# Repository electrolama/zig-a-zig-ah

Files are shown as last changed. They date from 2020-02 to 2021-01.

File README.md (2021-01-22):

# zig-a-zig-ah

zig-a-zig-ah! (zzh, for short) is little USB-stick form factor dev board for multiprotocol RF tinkering. It utilises the TI CC2652R multi-standard wireless MCU and a USB-UART chip with a few more goodies.

Details at [electrolama.com/p/zzh](https://electrolama.com/projects/zig-a-zig-ah/).

Pre-assembled boards for sale [on our Tindie store](https://www.tindie.com/stores/electrolama/).

**Need help with your Tindie purchase?** Please send an email to support@electrolama.com. Github issues are not the right place for customer support and we do not monitor them.

zzh is designed by Electrolama / Omer Kilic and licensed under the [Solderpad Hardware License 2.0](https://solderpad.org/licenses/SHL-2.0/).

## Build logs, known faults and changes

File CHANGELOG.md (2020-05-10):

Revision A - 10/05/2020
- Initial release

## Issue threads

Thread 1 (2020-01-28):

cc2652rb, baw resonator

zigastegu, 2020-01-28:
Hi, it seems RB does not need XTAL, as it has Integrated Bulk Acoustic Wave (BAW) resonator.
Don't know about price difference and avalability.
Would it make a difference for pcb size?
https://www.ti.com/sitesearch/docs/universalsearch.tsp?searchTerm=cc2652rb

omerk, 2020-02-01:
Hey @zigastegu,

Looks like samples are available but not GA just yet, price comparison from the TI Store:

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

PCB real estate wise, doesn't make a huge difference for zzh as the form factor is dictated by the [enclosure chosen](https://twitter.com/OmerK/status/1219025454344146945).

Pushed the draft design files in the repo, let me know if you spot anything out of the ordinary :-)

Closed 2020-02-01.

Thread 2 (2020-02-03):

Somebody tried it?

guitar9, 2020-02-03:
Does somebody tried it out?
Does it work?
What are the plans for future?

sermayoral, 2020-02-06:
@guitar9 the device is in desing stage, so it does not work yet, but it promises... :-)

omerk, 2020-02-16:
That is correct, waiting on PCBs and parts to verify the design at the moment.

Keep an eye on [this Twitter thread](https://twitter.com/OmerK/status/1212864418155028480) for the latest info.

Closed 2020-02-16.

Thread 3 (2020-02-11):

Help components eletronics

pedroborges1, 2020-02-11:
Good,  i am interested in this zigbee pen Zig-a-zig-ah.

you can send me a list of the electronic components you used ?

how do you flash this zigbee pen Zig-a-zig-ah ?

omerk, 2020-02-16:
Hi @pedroborges1,

This is an untested, work-in-progress design. If you're interested in the BOM, the design files are in the repo and you can open them with EAGLE.

Keep an eye on [this Twitter thread](https://twitter.com/OmerK/status/1212864418155028480) for the latest info.

pedroborges1, 2020-02-16:
thanks you ,

I already have the  zig-a-zig-ah[1]/ Revision A[2] eagle file .

but there is another folder name debug-adapter.

I just need the zig-a-zig-ah / revision A ?

the file is not there Bom ?

Citando Omer Kilic <notifications@github.com>:

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

Ligações:
---------
[1] https://github.com/electrolama/zig-a-zig-ah
[2] https://github.com/electrolama/zig-a-zig-ah/tree/master/Revision%20A
[3] https://github.com/pedroborges1
[4] https://twitter.com/OmerK/status/1212864418155028480
[5]
https://github.com/electrolama/zig-a-zig-ah/issues/3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
[6]
https://github.com/notifications/unsubscribe-auth/AOQ2NE62XLFQWUG6HLLSLVLRDF3IVANCNFSM4KS72SWQ

omerk, 2020-02-16:
As I've said, this is still a work in progress so I have not yet released anything other than the currently untested design files. If you're interested in building one at this stage you are going to have to go through what is in the repo and figure it out yourself.

pedroborges1, 2020-02-16:
thank you ,when you are finished let me know .

Citando Omer Kilic <notifications@github.com>:

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

Ligações:
---------
[1]
https://github.com/electrolama/zig-a-zig-ah/issues/3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
[2]
https://github.com/notifications/unsubscribe-auth/AOQ2NE3PXWLA5DXF66ANX23RDG6BFANCNFSM4KS72SWQ

pedroborges1, 2020-02-18:
good, but have you tested this zig-a-zig-ah?

how did the flash zig-a-zig -ah ?

Citando Omer Kilic <notifications@github.com>:

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

Ligações:
---------
[1]
https://github.com/electrolama/zig-a-zig-ah/issues/3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
[2]
https://github.com/notifications/unsubscribe-auth/AOQ2NE3PXWLA5DXF66ANX23RDG6BFANCNFSM4KS72SWQ

pedroborges1, 2020-07-01:
good, i used an ikea repeater for the zigbee network, but even so a
sensor sometimes stops working.

I think the signal doesn’t reach that sensor well, which is the one
that’s farthest away.

some solution to improve this ?
 

Citando pedro <pedrofilipe32@sapo.pt>:

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

Ligações:
---------
[1]
https://github.com/electrolama/zig-a-zig-ah/issues/3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
[2]
https://github.com/notifications/unsubscribe-auth/AOQ2NE3PXWLA5DXF66ANX23RDG6BFANCNFSM4KS72SWQ

Closed 2020-02-16.

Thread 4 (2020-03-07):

Raspberry hat

pimvanpelt, 2020-03-07:
Thanks for your work @omerk and I've subscribed to your mailing list for updates when you've tested your first Revision A in this repo.
When you're a bit further along, I suggest building a raspberry pi hat, as many folks will be using those to build their zigbee networks. I can contribute it (design it, order/test them and report back). Let me know if you'd be willing to accept that and I'll wait for you to confirm your current approach and send you a PR.
I think it would be good for the community to have these 26x2 boards in the same place and using the same firmware/pinout/etc.

omerk, 2020-03-08:
Hey @pimvanpelt, thanks for dropping by!

I've been busy testing today, you can find an update [on the project page](https://electrolama.com/projects/zig-a-zig-ah/).

With regards to the Raspberry Pi hat, not sure if you have seen [this](https://electrolama.com/projects/zoe/)? I have not yet pushed it online yet but I do have a version of zoe (zoe2, if you will) that merges the two projects together. Does that sound similar to what you had in mind?

pimvanpelt, 2020-03-09:
Yes, your zoe2 as a marriage of CC2652 and POE adapter looks like a
wonderful outcome to me, particularly because I do indeed use POE in my own
deployment.
Feel free to close this now, or once you have a prototype. Happy to buy a
dozen or so from you or make myself, as you prefer.

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

--
Pim van Pelt <pim@ipng.nl>
PBVP1-RIPE - http://www.ipng.nl/

omerk, 2020-03-10:
Keep an eye on https://electrolama.com or [Subscribe to the mailing list](https://mailchi.mp/1746be86dd81/electrolama) to get updates when I publish new projects.

Closed 2020-03-10.

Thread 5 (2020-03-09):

[SUGGESTION] Team up with zigpy-cc and/or zigpy-znp projects to beta-test Zig-a-zig-ah with ZHA in Home Assistrant

Hedda, 2020-03-09:
@omerk Can I suggest that @electrolama try to reach out to @sanyatuning & @Adminiuga & @puddly about collaborating and teaming up to beta-test your "Zig-a-zig-ah!" USB-stick together with the zigpy-cc and/or zigpy-znp projects for using Texas Instruments CC2652 based Zigbee adapters with the ZHA integration in Home Assistant?

- https://github.com/sanyatuning/zigpy-cc/
- https://github.com/zha-ng/zigpy-znp
- https://github.com/puddly/zigpy-znp

As I understand it zig-a-zig-ah by Electrolama / Omer Kilic as well as zigpy-cc by @sanyatuning and zigpy-znp @Adminiuga & @puddly are only spare-time hobby projects but still I think that teaming up might give both projects some positive recognition in the Home Assistant community which might attract more developers and willing alpha/beta-testers from the community to come help out with both these projects which in the long run could benefit all users wanting ZHA to become more mature and working with more hardware than today.

- https://www.home-assistant.io/components/zha/

marv, 2020-03-09:
Great suggestion! I'd love to get involved as well if I can be of any help. I've been following both projects for the last week with great interest and been contemplating about ordering some zig-a-zig-ah boards myself to test things, but thought I wait for @omerk first test results. Now that the design is verified to work, i'll try to find time for that

puddly, 2020-03-09:
The [TI LAUNCHXL-CC26X2R1](https://www.zigbee2mqtt.io/information/supported_adapters.html#texas-instruments-cc26x2r1) uses the exact same SoC and people have had good luck with it using [zigbee2mqtt/zigpy-cc](https://github.com/Koenkk/zigbee2mqtt/issues/1429). It's been powering my entire network of 30+ devices for many weeks now so this adapter *should* work out-of-the-box when flashed with the same firmware.

Gamester17, 2020-03-10:
This kind of relate to my suggestion to donate money to existing Zigpy and ZHA developers for them to buy TI CC based hardware in order to be able to help with the development, see here:

https://github.com/zigpy/zigpy/issues/276

My thinking is if more developers with proven personal interest Zigpy or ZHA owed TI CC hardware then they might have a greater incentive to volunteer their time and skill for developing this.

I am not a developer myself, however, I am willing to make a small donation for this cause because believe that the concept of Zigpy or ZHA for Home Assistant will benefit the community in the long.

omerk, 2020-03-10:
Hey all,

Definitely keen to collaborate (power of open source hardware and software!) and can happily provide some prototypes if and when you have time to test it with your corresponding projects.

I am reasonably confident with the design but will be doing some further testing this weekend and have enough parts for a couple of prototypes that I can hand populate/reflow. As you can imagine hand populating these boards take a good amount of time so the first few units are very precious 😄

Feel free to reach out (<myfirstname>@electrolama.com) if you'd like to play with some prototype hardware!

Cheers,
Omer.

Hedda, 2021-01-13:
@omerk Can I suggest that you reach out to @puddly and @sanyatuning  about prototype/alpha/beta/reference-testing your upcoming "zzh-p" (CC2652P USB) and "zoe2" (CC1352P shield) adapters together with zigpy? Please also see https://github.com/zigpy/zigpy-znp/issues/55

Closed 2020-03-10.

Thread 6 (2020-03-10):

[SUGGESTION] Market and sell an initial of batch Zig-a-zig-ah! adapters via the Crowd Supply site?

Hedda, 2020-03-10:
@omerk I like to suggest that you market and sell an initial small batch of your Zig-a-zig-ah! USB-adapters via the **Crowd Supply** crowdsourcing site for electronics hardware at [crowdsupply.com](https://www.crowdsupply.com)

- https://www.crowdsupply.com

@omerk I understand that you already have existing plans to sell hardware via Tindie. Crowd Supply is similar but different than Tindie in that Crowd Supply is not just a marketplace but specifically, a crowdsourcing platform which has staff that will actively help you with advice on running a crowdsourcing campaign for funding, manufacturing, and marketing.

Most importantly, Crowd Supply has a great international community so I think that also launching a crowdsourcing campaign on Crowd Supply would help you grow a much larger community around Electrolama and the Zig-a-zig-ah project. Many electronics products have initially first launched on Crowd Supply then only after proven successful and gaining experience of running a small crowdsourcing campaign with a smaller batch next launch larger crowdsourcing campaigns with a more finished version of the same or similar products on Kickstarter and/or Indiegogo.

- https://www.crowdsupply.com/about

I have no personal affiliations with **Crowd Supply** or its owers/staff, but I backed a couple of projects there myself and know that their site is meant exactly for helping crowdsource funds and initial launch of a small batch of this type of early version hobby-class hardware kits meant for developers and advanced users who are willing to accept bleeding-edge hardware which might not yet be a finished product.

Personally I can recommend that you compare this μArt hardware by Karoly Pados which I backed:

- https://www.crowdsupply.com/pylo/muart

I think that his launch for a small initial batch of μArt (pronounced "Muart") on Crowd Supply was a perfect example of how a crowdsourcing campaign for this type of niche electronics hardware should be handled before its a mature product.

omerk, 2020-03-10:
Hey @Hedda, thanks for reaching out.

I am familiar with Crowdsupply and looking at distribution/logistics is on my list of things to do for the weekend, after I do some further testing with the prototypes so that I can issue files for manufacturing a small batch.

Getting the design verified is my current priority, rest will follow soon after 😄

Cheers!

Hedda, 2020-03-11:
@omerk Cool! Regardless if you go with that or not I still highly recommend that you read through μArt updates by Karoly Pados as a great example on how to run and update the community during such a campaign, so do checkout update history here https://www.crowdsupply.com/pylo/muart/updates

Closed 2020-03-10.

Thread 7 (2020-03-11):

[NEW PROJECT SUGGESTION] Zigbee 3.0 and Z-Wave 700 platform series combo USB-stick

Hedda, 2020-03-11:
Hi Omar! I follow you on Electrolama, hope it is OK to submit this as a suggestion for a new project.

Suggest you consider making a "combo" USB-stick supporting both Zigbee 3.0 & Z-Wave 700 series.

I believe that should be a good market for a "combo" USB-stick if Zigbee 3.0 coordinator & Z-Wave 700 (Gen7) platform series controller could be offered as a combination on the same USB-stick and it was less expensive to buy then to buy a separate USB-sticks for each protocol. As you probably know both Zigbee 3.0 and the Z-Wave 700 platform series are backwards compatible with previous versions of those protocols, so a such combo USB-stick could probably be marketed as the most compatible USB-stick for DIY home automation controllers in the world.

Not sure if you knew but there is a very popular combo USB-stick already available, it however only supports Zigbee HA 1.2 and Z-Wave 500 (Gen5) series; Nortek GoControl QuickStick Combo Model HUSBZB-1 (Zigbee & Z-Wave USB Adapter) is supported natively by Home Assistant's built-in ZHA and Z-Wave integrations. As I understand it, that HUSBZB-1 is based on two separate Silicon Labs chips for Zigbee and Z-Wave, and it presents itself to the operating system as two separate serial adapters. "The Model HUSBZB-1 is a USB stick that houses both a Z-Wave and Zigbee radio. Designed for OEMs that want to provide dual functionality when being used with a host device.":

https://www.nortekcontrol.com/products/2gig/husbzb-1-gocontrol-quickstick-combo/

Silicon Labs released a UZB-7 / UZB7 based on EFR32ZG14 as a reference design for making Z-Wave 700 platform series USB-stick controllers.

https://www.silabs.com/documents/public/data-sheets/DSH14483.pdf

Silicon Labs also has Zigbee chips like EFR32MG13 (example: EFR32MG13P732F512GM32-C) and others design to be used in a Zigbee coordinator.

https://www.silabs.com/wireless/zigbee

As I understand it, both those chips belong to the "Gecko" series by Silicon Labs.

Anyway, chips from Silicon Labs would be the obvious choice for a combo USB-stick since they own the Z-Wave specification and are also according to them the leading provider of Zigbee solutions as as as for Bluetooth solutions.

https://www.silabs.com/products/wireless/mesh-networking/z-wave/700-platform

PS: I don't have the skills to contribute to a hardware design but I would definitely buy one or back such a combo USB-stick if was launched as a campaign on a popular global crowdfunding platform.

omerk, 2020-03-25:
Thanks for the links and background info @Hedda

I must admit I am a lot more familiar with Zigbee than Z-Wave so that is what I am focusing on with this design but once zzh gets a bit more mature and I am looking for my next weekend project, I will certainly revisit this discussion!

Closed 2020-03-25.

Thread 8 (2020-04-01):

[REQUEST] Create a small adapter-board for connecting the standard CC-DEVPACK-DEBUG board to Zig-a-zig-ah USB-stick?

Hedda, 2020-04-01:
@omerk Can I suggest or request that you please consider also creating a matching small adapter-board for connecting Texas Instruments standard CC-DEVPACK-DEBUG board (XDS110 Debug Probe) to Zig-a-zig-ah USB stick?

CC-DEVPACK-DEBUG board meaning the XDS110 Debug Probe that is also included in the CC2652 Launchpad board (LAUNCHXL-CC26X2R1):

- https://www.digikey.com/product-detail/en/texas-instruments/CC-DEVPACK-DEBUG/296-42039-ND/5232199
- https://processors.wiki.ti.com/index.php?title=CC13xx_CC26xx_Tools_Overview#XDS110_2

That is since the Zig-a-zig-ah USB-stick has a non-standard debug-port it would preferably be nice to have a simple adapter-board for connecting Texas Instruments standard CC-DEVPACK-DEBUG board to it for debugging purposes. Perhaps an adapter similar to that is commonly sold with CC2531 USB sniffer dongles for connecting a CC-Debugger to them, (those referred to as "downloader cable" by Zigbee2mqtt):

 - https://www.zigbee2mqtt.io/getting_started/what_do_i_need.html
 - https://www.zigbee2mqtt.io/getting_started/flashing_the_cc2531.html

For reference; @turboproc mentioned here that he has also designed/created a small adapter-board for connecting the standard CC-DEVPACK-DEBUG board to his own prototype CC2652 USB dongle:

https://github.com/Koenkk/zigbee2mqtt/issues/1429#issuecomment-606814358

turboproc, 2020-04-01:
Regarding the adapter, that's indeed what I did: tiny  board that clicks in the CC-DEVPACK-DEBUG board and has that connects with a small cable (2 x 3 pin 1.27mm pitch) into the dongle. Used the same pin-out on that side at he Zig-a-zig-ah to avoid again another non standard solution.

Hedda, 2020-04-01:
@turboproc Are you maybe willing to share your design layout & BOM, etc. as open-source hardware?

turboproc, 2020-04-01:
Sure, no problem. Give me some time to push it to Github.

omerk, 2020-04-01:
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

I've committed the files for this adapter [2 months ago](https://github.com/electrolama/zig-a-zig-ah/tree/master/Debug-Adapter), should have checked the repo @turboproc :-)

Closed 2020-04-01.

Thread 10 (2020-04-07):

[INFORMATION] Zig-a-zig-ah USB-stick should also be compatible with turboproc's Zigbee dongle adapter for TI CC-DEVPACK-DEBUG board

Hedda, 2020-04-07:
@omerk FYI, just a piece of compatibility information, the Zig-a-zig-ah USB-stick should also be compatible with the Zigbee dongle adapter for TI CC-DEVPACK-DEBUG board designed by @turboproc

- https://github.com/turboproc/Zigbee-dongle-adapter

The 6 pin connector on the Zig-a-zig-ah USB-stick should also match both the [CC1352-based Zigbee USB-dongle](https://github.com/turboproc/Zigbee-USB-dongle) by @turboproc and the [CC2652-based Zig-a-zig-ah USB-stick](https://github.com/electrolama/zig-a-zig-ah) by @omerk allowing easy connection to the TI CC-DEVPACK-DEBUG board that allow these Zigbee USB dongles to be programmed through the CJTAG interface.

- https://github.com/turboproc/Zigbee-USB-dongle
- https://github.com/electrolama/zig-a-zig-ah

omerk, 2020-05-07:
Good to know although there is already a [debug-adapter board in the repo](https://github.com/electrolama/zig-a-zig-ah/tree/master/Debug-Adapter).

Closed 2020-05-07.

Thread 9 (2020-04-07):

[REQUEST] CAD-design of CC2652 USB-stick housing/enclosure and STL-files for editing and 3D-printing?

Hedda, 2020-04-07:
@omerk  Anyone working on an open-source CAD-design of a USB-stick housing/enclosure specifically made for CC2652 USB-sticks and if so would be willing to share their designs in STL file-format to enabling editing the design by others and 3D-printing?

One can, for example, get many designs and files for CC2531-based USB-dongles/USB-adapters (with or without antenna) on Thingiverse, example:

- https://www.thingiverse.com/thing:3948643
- https://www.thingiverse.com/thing:3646828
- https://www.thingiverse.com/thing:3532598
- https://www.thingiverse.com/thing:3731958

One can also buy professionally made injection moulding housings/enclosures from China via Alibaba or Aliexpress that one can take inspiration from, example:

- https://aliexpress.com/item/4000134201124.html
  - https://ae01.alicdn.com/kf/Hfb070d72fc45440497dce7d04e59d6b7d.jpg
- https://aliexpress.com/item/32855419632.html
  - https://ae01.alicdn.com/kf/H326a2ad3cfe64a318083102b0df62cd5N.jpg
  - https://ae01.alicdn.com/kf/H01eca8f47cd64bfd975738c1a4c30553i.jpg
- https://aliexpress.com/item/33007327270.html
- https://aliexpress.com/item/32852997963.html
- https://aliexpress.com/item/32690180597.html
- https://aliexpress.com/item/32847892743.html
  - https://ae01.alicdn.com/kf/HTB1K83IeXHM8KJjSZFwq6AibXXaD.jpg

By the way, I am not sure about English terminology for this, when talking about an exterior/outer protective covering for interior/inner electronic equipment in the specific context of a USB-dongle/USB-adapter like the Zig-a-zig-ah USB-stick, is the keyword called; enclosure, housing, casing, cover, case, box, shell, or another descriptive name that might be more correct?

- https://en.wikipedia.org/wiki/Housing_(engineering)
- https://en.wikipedia.org/wiki/Electrical_enclosure
- https://en.wikipedia.org/wiki/Computer_case

Hedda, 2020-04-07:
Disclaimer: I have also posted the same request/question to @turboproc on https://github.com/turboproc/Zigbee-dongle-adapter/issues/1

omerk, 2020-05-07:
zzh uses a very common off-the-shelf "usb shell" enclosure from China so unfortunately I don't have any STLs to share as I didn't design it.

Happy to accept contributions from anyone with the CAD experience to release an open-source enclosure for it though, ping me if you need any dimensions/3D data exported.

Closed 2020-05-07.

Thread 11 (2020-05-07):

[QUESTIONS] Plans on manufacturing, crowdfunding and/or selling none-prototype version of Zig-a-zig-ah (ZZH) dongles?

Hedda, 2020-05-07:
@omerk Read in https://github.com/Koenkk/zigbee2mqtt/issues/1429 that you plan on setting up a Tindie store for Zig-a-zig-ah (ZZH) dongles and was curious on your plans for selling and shipping the USB-stick adapter as a "finished plug-and-play product" there as not seen any updates on your Twitter account or the Electrolama site.

Mostly I was wondering if you already have funding and manufacturers lined up for making a finished product or are you doing a crowdfunding campaign? Also, where do you think you will be shipping it from? I'm asking for myself as an EU (European Union) customer, Sweden to be exact.

Regardless of how you proceed, please ship the product with a nice plastic housing/enclosure/shell/chassis which will be easy to open and close for modification, as related to the request in https://github.com/electrolama/zig-a-zig-ah/issues/9 you can buy professionally made injection moulding housings/enclosures from China but I am not sure they are to open and close over and over again without breaking the fastenings.

zigastegu, 2020-05-07:
Onboard bootloader sholod enable flashing new fw without opening enclosure or so I have read on: https://electrolama.com/projects/zig-a-zig-ah/

Do you have any other use cases for opening enclosure?

omerk, 2020-05-07:
Hi @Hedda,

Not interested in crowdfunding, the first batch should go up on Tindie at some point this weekend (at least, submitted for their approval). Sign up to the [mailing list](https://electrolama.com/list) to get an update when everything goes live.

Here's a photo of the enclosure and the antenna that will ship with the units purchased on Tindie, it's a snug fit case but certainly would last the few times that you might need to open the unit if you want to program the device

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

omerk, 2020-05-07:
@zigastegu If you want to program the board, you will still need to press the "BSL" button as you're plugging the device in to trigger the bootloader (requiring you to open the case).

I've asked about triggering the bootloader from a running program on the [TI forums](https://e2e.ti.com/support/wireless-connectivity/zigbee-and-thread/f/158/t/902829), let's see what they say.

Realistically, unless you are a firmware developer you shouldn't have to worry about opening the case to access the button as once you program the board and set up your network, you will leave things as they are. If you are indeed developing firmware and don't want to worry about the case, I suggest using the bare board without the case.

mar565, 2020-05-07:
@omerk can you already Tell us the price?

omerk, 2020-05-10:
Listing submitted to Tindie, once approved it will go live on https://www.tindie.com/products/electrolama/zzh-cc2652r-multiprotocol-rf-stick/

Hedda, 2020-05-11:
> Onboard bootloader should enable flashing new fw without opening enclosure or so I have read on: https://electrolama.com/projects/zig-a-zig-ah/
>
> Do you have any other use cases for opening enclosure?

Firmware developers with the debug adapter require access to the board for debugging, see:

https://github.com/electrolama/zig-a-zig-ah/tree/master/Debug-Adapter

Also, if you brick it then you need to press the "BSL" button to trigger boot to the bootloader.

Hedda, 2020-05-12:
@omerk Out of stock / Sold out already? Checked yesterday before went to bed and was not live then:

https://www.tindie.com/products/electrolama/zzh-cc2652r-multiprotocol-rf-stick/

Closed 2020-05-10.

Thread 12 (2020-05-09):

Some suggestions for a future revision of the board

puddly, 2020-05-09:
(copied from https://github.com/zha-ng/zigpy-znp/issues/10)

Thanks for the awesome board! I'm seeing an average LQI improvement of 30% compared to the bulkier LAUNCHXL-CC26X2R1.

Here are some suggestions for future revisions of the board:

1. Would you consider using a USB-serial chip by FTDI or Silicon Labs? The CH340 is the only USB-serial chip that consistently causes a kernel panic on my MacBook and is overall unreliable in my experiences with random dev kits. I'm running kernel 4.14.176 on my ODROID XU4 and the ZZH stick needs to be re-plugged a few times in a row to respond to any serial communications, unless it's plugged into a USB extender (!?). I have half a dozen other USB devices plugged in at any given time and have never had this problem except with devices using the CH340.

2. While a minor detail, holding down the flash button while inserting the stick is difficult with the button mounted horizontally and near the male USB-A connector. It would be a bit easier to flash if the button was mounted near the rear of the board next to the antenna.

3. I'm not sure if there's a huge price difference for you but including one of those bendable and rotatable 2.4Ghz antennas would make it easier to mount. Most of my USB devices are plugged into a powered hub with the ports sticking straight up and the fixed right-angle antenna connector makes mounting a little difficult.

If I end up making a case for it I'll definitely make a pull request with the STL. If you have a moment, could you upload an SVG version of your logo to this repository?

omerk, 2020-05-10:
Hey @puddly, great to hear you are up and running and thanks for the comments!

Addressing your points:

1) zzh originally had CP2102N but had to find a replacement as it simply wouldn't fit the layout once I picked the enclosure. I did look at FT230X and FT234XD (the 'runner-up') but at many times the cost of CH340E and with much better driver support over the last year or so for CH340E, the decision was made.

The assumption here is that majority of the users of zzh will be using Linux and probably on a popular SBC (like a Raspberry Pi) that will have an up-to-date kernel. In the many months of testing I did with both Raspberry Pi and an Ubuntu box, I never had driver issues. I know @Koenkk had an issue initially with the drivers but that was solved with him updating his box.

Now of course this isn't an attempt at not acknowledging the issues you are having, just providing the rationale behind the design decision. For macOS, unfortunately I can't really comment as I don't have any Macs around but for your XU4, can I ask perhaps you give a more recent kernel (if available) a go? [Some recent fixes in the kernel driver](https://github.com/torvalds/linux/commits/master/drivers/usb/serial/ch341.c) did improve the situation quite a bit. If you have the willpower and the time to tinker with the kernel on your XU4, perhaps we can get to the bottom of it? In the meantime, I can happily send you the hacked-with-the-FT234XD board I have in my box of prototypes. It won't look pretty but it sure is another collectors' piece :-)

2) I ordered a dozen or so button samples, some side mounted ones included, but it came down to picking this current one because it had a nice click and actually felt like a button (a problem with tiny buttons!). I actually wanted to use the side mounted one used on the TI Launchpads but not enough space :(

3) The antenna I picked sits nicely in the middle of a size-cost-performance triangle, size being the deciding factor. I couldn't find a small-enough 'bendable' antenna so decided to go for this fixed version instead, based on the assumption that the following would be the typical use case:

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

I am still looking for a small *and* bendable antenna that is sensibly priced, once I find it we can then issue it as a running change for boards shipped. The beauty of the detachable antenna is that if it gets on your nerves too much, you can change it.

Always difficult defining a product to satisfy all use cases and it comes down to making assumptions (like the ones discussed above) and hoping you were right. I guess we will find out given that this is an open source project with an issue tracker :-)

Cheers!

Adminiuga, 2020-05-10:
well, since there's SMA connector you could get any antenna you'd like aliexpress. Just make sure it is SMA Male connector for antenna.

eg https://www.aliexpress.com/item/33044689298.html

Adminiuga, 2020-05-11:
@puddly are you on armbian? I'm running my prod on xu4 as well and this is going be a show stopper. Gonna try switching kernels to 5.4

puddly, 2020-05-11:
1. My development and production setup is definitely not common so no worries, I'm just documenting the issues I have. If I run into it again and figure out a way to fix it I'll post an update.

2. I was thinking just moving the button closer to the antenna, so you can keep it pressed more easily while inserting the stick. It does have pretty good tactile feedback for its size.

3. I just tested out one of those bendable antennas from a 2.4GHz wireless card and the LQI was reduced quite a bit, though not as much as with the right-angle antenna pointed the wrong way.

Hedda, 2020-05-11:
Possible to replace CH340E with one that has flashable EEPROM so strings/VID/PID can be customized?

Would be both more user-friendly, to be able to for example script plug-and-play auto-detection, and more professional if the description for the serial port device was shown as example:

 "Zig-a-zig-ah USB-dongle v1.0.0"

As per the original suggested in https://github.com/zha-ng/zigpy-znp/issues/10 by @Adminiuga

> @omerk is it possible to customize the USB-Serial chip, so it provides a more specific description for serial port device? Currently I"m getting generic:
> `usb-1a86_USB2.0-Serial-if00-port0 -> ../../ttyUSB0`

Hedda, 2020-05-11:
> If I end up making a case for it I'll definitely make a pull request with the STL. If you have a moment, could you upload an SVG version of your logo to this repository?

@puddly Please also see related CAD-design request in https://github.com/electrolama/zig-a-zig-ah/issues/9

Hedda, 2020-05-11:
> While a minor detail, holding down the flash button while inserting the stick is difficult with the button mounted horizontally and near the male USB-A connector. It would be a bit easier to flash if the button was mounted near the rear of the board next to the antenna.

@omerk Regardless of button location on the board, a tip follow the industry-standard design and drill a small hole through the enclosure/case where the button is located to let users be able to press the button with a paper-clip

https://www.google.com/search?q=paper+clip+reset+button&tbm=isch

Again, having a "Reset Hole" purposely design to be pressed via a paper-clip is the industry-standard.

Hedda, 2020-05-11:
SMA or RP-SMA (Reverse-Polarity SMA) is basic but important information when buying an antenna:

https://en.wikipedia.org/wiki/SMA_connector

@omerk Which exact type of SMA connector design does the ZZH board have on it?

Do ZZH board have a Standard-Polarity SMA or a Reverse-Polarity ("RP") SMA female connector?

> well, since there's SMA connector you could get any antenna you'd like aliexpress. Just make sure it is SMA Male connector for antenna.
>
> eg https://www.aliexpress.com/item/33044689298.html

I can personally recommend "Delock" branded Wi-Fi antennas which can be bought in EU & USA.

https://www.delock.com/produkte/G_1468_Antenna.html

I have no personal affiliations but in the European Union you can buy Delock antennas from Conrad

https://www.conrad.com

puddly, 2020-05-11:
Another issue I'm seeing (though probably not zzh-specific) is that I get nonstop routing and MAC failures with it plugged directly into my XU4. There are bulbs within a few feet of it I get errors such as these in response to any request, even with route discovery enabled:

```Python
AF.DataConfirm.Callback(Status=<Status.NwkNoRoute: 205>, Endpoint=1, TSN=18)
AF.DataConfirm.Callback(Status=<Status.MacChannelAccessFailure: 225>, Endpoint=1, TSN=15)
```
Plugging it into a hub an inch or two away fixes the issue. I'll try out some simple shielding and will see if it helps at all.

Adminiuga, 2020-05-11:
ChannnelAccessFailure  is pretty much a tail sign of RF interference. If it is fixed by keeping the board away from SBC, then we can conclude the noise is coming from the  SBC which is frankly quite expected.  ConBees are susceptible  to the very same issue and that's why they always recommend to use an usb extension cable.
I wonder how many people complaining about range issue, could fix them  by using an usb extension.  I assume all are susceptible to this issue, just some  adapters are not providing this feedback.

Hedda, 2020-05-12:
Tip regardless of antenna is to use at least a 1-meter USB-extension cable for all radio adapters. If use USB-extension cable then gets it away from most SBC or computers WiFi and Bluetooth interference.

Hedda, 2020-05-12:
@omerk here is a "must-read" article about analyzing antennas if want to be sure before deciding:

- https://tinkerman.cat/post/analyze-your-antennas-using-an-aai-n1201sa/

It recommends buying theN1201SA by Accuracy Agilty as is a cheap but incredibly useful tool:

- http://s.click.aliexpress.com/e/bVPlgjT6
- https://amzn.to/2VqBlW5

That article is written by Xose Pérez (a.k.a. Tinkerman) who also develops ESPurna FW for ESP8266:

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

sjorge, 2020-06-27:
> 1. Would you consider using a USB-serial chip by FTDI or Silicon Labs? The CH340 is the only USB-serial chip that consistently causes a kernel panic on my MacBook and is overall unreliable in my experiences with random dev kits. I'm running kernel 4.14.176 on my ODROID XU4 and the ZZH stick needs to be re-plugged a few times in a row to respond to any serial communications, unless it's plugged into a USB extender (!?). I have half a dozen other USB devices plugged in at any given time and have never had this problem except with devices using the CH340.

Just going to give this a +1 here too :) Omerk is already aware of my preference, as I am not using linux (or freebsd) I am currently trying to write a driver for CH340 and boy its and oddball chip.

omerk, 2020-06-27:
zzh-p will use FT231 that will allow us customise strings and also auto-reset/put device in BSL mode via DTR/RTS pins exposed.

No plans for change on zzh though.

copystring, 2020-06-27:
Nice. I was about to ask about this to allow nice udev rules (all CH340 have the same serial). Exciting!

svh1985, 2020-09-18:
I also have a small suggestion;
I'm not sure if the provided plastic case is custom designed or off-the-shelf, but adding a small hole to allow us to press the BSL button would be very nice. Getting the case off is hard and this makes programming possible without removing the case.

Hedda, 2021-01-13:
@omerk Any news on your CC2652P based "zzh-p" and if it will soon be available for sale or not?

omerk, 2021-01-22:
Hi all, lots of comments to address but as a summary:

There will be two versions zzh with CC2652P: zzhp and zzhp-lite. Both will use the same firmware, zzhp-lite will be module-based (PCB antenna) and zzhp will be a custom board similar to the first draft screenshot you linked above (external antenna). I've also managed to squeeze in a few more goodies in zzhp and will be updating the website soon. Release date not set yet but it's very soon.

@svh1985 and many others requested a pre-drilled hole. The last couple of (and all future) batches will ship with cases that are pre-drilled:

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

You'll also notice that we now have a swivel antenna, another requested feature.

Both drilled cases and that newer antenna were things I wanted from the get go but needed to hit a certain MOQ before I could get them. We're there now 🙂

Closed 2021-01-22.

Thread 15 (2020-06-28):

No Signal in Z2M when using a different antenna

kennymc-c, 2020-06-28:
When I connect the zzh to different antenna (dual band WiFi +9dbi), Z2M seems to have problems with reception. There are simply no signals coming in. According to dmesg, the adapter has been detected by the system. As soon as I reconnect it to the supplied antenna, the signal is coming back. Since I use the same type of antenna with a CC2530 router, I assume that the antenna itself is suitable for this. I have attached a zigbee-herdsmann debug log that might help:

https://pastebin.com/k4wAtciK

puddly, 2020-06-28:
The zzh has a female SMA connector. Make sure your antenna is not a male RP-SMA, which will still screw on but will not actually act as an antenna:

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

kennymc-c, 2020-06-28:
Thanks, that should be the reason. My antenna is also female. I just realized now when I saw the connection. Sorry, I could have figured it out myself.

Closed 2020-06-28.

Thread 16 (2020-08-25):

[SUGGESTION] Team up with pipiche38 who is developing a zigpy plugin for Domoticz

Hedda, 2020-08-25:
@omerk (Omer Kilic) Can I suggest that you (and @electrolama ) try to reach out to @pipiche38 (Patrick Pichon) about possible collaborating and teaming up to test your "Zig-a-zig-ah!" USB-stick together with the new Zigbee implementation for Domoticz that he is developing using [zigpy](https://github.com/zigpy/zigpy)?

* https://github.com/pipiche38/Domoticz-Zigpy/

Please also see respective suggested posted to pipiche38 here:

https://github.com/pipiche38/Domoticz-Zigpy/issues/1

If you omerk (Electrolama) could donate one or two of your "Zig-a-zig-ah!" USB-sticks to him then maybe he that can help @pipiche38 developing effort as it would give him the possibility to also test both [zigpy-cc](https://github.com/zigpy/zigpy-cc) and [zigpy-znp](https://github.com/zha-ng/zigpy-znp) radio libraries for zigpy to try out their compatibility with newer Texas Instruments CC2652 based Zigbee adapters as zigpy can support many different adapters. It could perhaps later even be used as a reference adapter. No strings attached of course as these are still hobby projects at their core with only one developer so far.

https://github.com/zigpy/zigpy

pipiche38 is still in a very early stage of developing his "Domoticz-Zigpy" plugin for [Domoticz](https://www.domoticz.com) (a free and open-source home automation software), I understand in fact the project is so a such early in development that is not yet usable, however, I read on Domoticz community forum that he currently only has access to ZiGate Zigbee adapters (this as pipiche38 is also the developer of an existing ZiGate plugin for Domoticz). So at least we know that pipiche38 already has the experience and skills to develop Zigbee plugins for Domoticz.

* https://github.com/pipiche38/Domoticz-Zigate-Wiki/blob/master/en-eng/Home.md

* https://www.domoticz.com/wiki/Zigate

As I understand it zig-a-zig-ah by Electrolama, zigpy, Domoticz, and this new "Domoticz-Zigpy" plugin are all only spare-time hobby projects but still, I think that teaming up might give all involved projects some positive recognition in the Domoticz community and the whole home automation scene in general which might attract more developers and willing alpha/beta-testers from the community to come to help out with all these involved projects which in the long run could benefit all users wanting Zigbee in Domoticz to become more mature and working with more Zigbee hardware dongles than it is today.

omerk, 2020-08-27:
@pipiche38 Happy to support a fellow open-source Zigbee developer, if you would like me to send you a zzh stick please drop me an email (omer @ electrolama dot com) with your address.

pipiche38, 2021-12-14:
@omerk this is just to let you know that we have restarted the project to integrate Electrolama zzh key into Domoticz.
This will be done over the Domoticz-Zigate for which we will provide a zigpy layer and which will provide the support.

We will try to track the work over the Issue  [#888](https://github.com/pipiche38/Domoticz-Zigate/issues/888)

pipiche38, 2021-12-19:
@omerk just a quick update from our side, we are making very good progress on the zigpy-znp integration into the Domoticz-Zigate plugin

The main benefit is by using the zigpy-znp layer on top of the zzh key is to use the all development done already with Zigate and so getting all feature available right away.

we are now able to get the Domoticz (zigate) plugin connected to a zzh key, controlling the key ( seting permit to join, managing the Led ...) and capable to pair Aqara sensor as Bulbs from Ikea or LXEK.

Struggling with the ZDO zigpy-znp layer for now, but no real big issue

Will probably be join by one more developper/tester/documentation soon @jp_keros

Hedda, 2021-12-20:
> Struggling with the ZDO zigpy-znp layer for now, but no real big issue

@pipiche38  Off-topic but FYI check out related discussion with reply from puddly regarding ZDO -> https://github.com/zigpy/zigpy-znp/issues/108

jp-keros, 2021-12-20:
> Will probably be join by one more developper/tester/documentation soon @jp_keros

I'm involved.

pipiche38, 2021-12-27:
@omerk , just a quick update.

Project is progressing fast, here is the future home page: [ZigbeeforDomoticz](https://github.com/pipiche38/Domoticz-Zigate/tree/zigpy#readme) feel free to comment, update.

I there are some zzh users interested to be part of a testing community , please point them to me, we will for sure be interested to have a panel of end user testers.

Closed 2020-08-27.

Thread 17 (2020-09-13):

Very bad range after switching to zzh

kisseler, 2020-09-13:
I tried to modernize my zigbee2mqtt hardware by replacing the CC1352P-2 dev board by this new nice great form factor zzh dongle. After some tries I made it flashing the z2m firmware and wondered why I cannot pair any devices.

I turned out, I had to approach the dongle less than one meter to pair a device. That's more than disappointing. Setiing the system back to the CC1352P-2 hardware as coordinator, I was easyly able to pair devices from next room. I tried USB extension cable and unplugging other devices to reduce interference.

Anyone else here having that problem? I wanted to make my system more and more reliable, but with zig-a-zig-ah it seems to be not the right way. Or what am I missing?

Thanks for any hint!

omerk, 2020-09-13:
Hi @kisseler, please send me your Tindie order number to support@electrolama .com and we can go figure out what the problem is.

Closed 2020-10-17.

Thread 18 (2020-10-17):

New ZZH unable to pair any devices

magicdude4eva, 2020-10-17:
I just got the ZZH and wanted to replace my ConbeeII on a RPI4 (I flashed the current firmware via Mac)
```
./cc2538-bsl.py -p /dev/tty.usbserial-14320 -evw znp_CC26X2R1_LAUNCHXL_tirtos_ccs.hex
Opening port /dev/tty.usbserial-14320, baud 500000
Reading data from znp_CC26X2R1_LAUNCHXL_tirtos_ccs.hex
Your firmware looks like an Intel Hex file
Connecting to target...
CC1350 PG2.0 (7x7mm): 352KB Flash, 20KB SRAM, CCFG.BL_CONFIG at 0x00057FD8
Primary IEEE Address: 00:12:4B:00:21:60:01:6A
    Performing mass erase
Erasing all main bank flash sectors
    Erase done
Writing 360448 bytes starting at address 0x00000000
Write 104 bytes at 0x00057F980
    Write done
Verifying by comparing CRC32 calculations.
    Verified (match: 0x870fee48)
```

I have Zigbee2mqtt installed on latest HA (I uninstalled Zigbee2mqtt multiple times, deleted the configs and DB files, removed the stick) and I adjusted configs to either use `/dev/serial/by-id/usb-1a86_USB_Serial-if00-port0` or just `/dev/ttyUSB0` I am not able to see our scan any new devices (yes I added `rtscts: false`, changed pan_id, ext_pan_id and network_key).

Are there any limitations with regards to channels (I am running on channel: 25)?  In removed all Zigbee devices from my ConbeeII and during the ZZH setup reset the devices multiple times without success of finding or pairing.

Note: After uninstalling Zigbee2mqtt, deleting the database file, replacing the ZZH with the ConbeeII and rebooting HA, all the Zigbee devices are found (I literally just replace the port config pointing to the ZZH to the Conbee).

It does not look like the ZZH is dead-on-arrival, as I otherwise would be able not to flash it - or? I re-read the instructions multiple times (also tried ZHA with same results). Is there anything I missed?

omerk, 2020-10-17:
Hi @magicdude4eva, there are no limitations on what channels can be used. Sounds like there might be an issue with the antenna.

Please drop an email with your Tindie order number to support@electrolama.com and we can figure out a solution.

Closed 2020-10-17.

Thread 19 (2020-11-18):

[SUGGESTION] Team up with zoic21 who is developing ZGP support for zigpy

Hedda, 2020-11-18:
@omerk (Omer Kilic) Can I suggest that you (and @electrolama ) try to reach out to @zoic21 (Loïc Gevrey) about possible collaborating and teaming up to test your "Zig-a-zig-ah!" USB-stick together with the ZGP (Zigbee Green Power) implementation that he is developing for [zigpy (Zigbee stack abstraction library for Python)](https://github.com/zigpy/zigpy) to be used in both Home Assistant and Jeedom (as well as any other software that will also use the zigpy project in the future)?

https://github.com/zigpy/zigpy/pull/519

If you omerk (Electrolama) could donate one or two your "Zig-a-zig-ah!" USB-sticks to him then maybe that will help his developing effort as it would give him the possibility to test a TI CC2652 based Zigbee adapter like your with ZGP (Zigbee Green Power) implementation with the [zigpy-znp](https://github.com/zha-ng/zigpy-znp) radio libraries for Texas Instruments Z-Stack 3 adapters. It could perhaps later even be used as a reference adapter. No strings attached of course as these are still hobby projects at their core with only one developer so far.

https://github.com/zigpy/zigpy

As I understand it, today @zoic21 (Loïc Gevrey) only have a Silicon Labs based Zigbee adapter plus a ConBeee Zigbee adapter to test this implementation with and apparently, it requires protocol translation from each propitiatory API that different hardware manufacturers use on their Zigbee adapters.

PS: By the way, @zoic21 also happen to be the lead developer of Jeedom (open-source home automation software from France)

zoic21, 2020-11-18:
Hello,
Yes I only have conbee 2 (deconz key) en silicon labs key. I test ZGP on it and it's seem ok but I don't know how it's work on TI.
From what I saw on deconz and silicon labs there is a bit of decoding done by the key and for each key it is different.

Hedda, 2020-11-19:
@zoic21 this is only a request for Omer to donate a TI dongle hardware to you in order so that you can develop with it.

For the actual development of ZGP for TI in zigpy you will need to talk to zigpy-znp developers in https://github.com/zigpy/zigpy-znp/issues/47

th0m4sek, 2020-11-19:
I believe in yours good intentions but in my opinion this is not the way to ask for this kind of staff.
You can buy one and send it @zoic21 or donate money directly so he will buy it by himself.
I don't want to be disrespectful to anybody.
Peace.

Hedda, 2020-11-19:
@th0m4sek I disagree as the end result should benefit Electrolama/omerk.  Think of it based on these facts and extrapolations:

Electrolama/omerk sells his zig-a-zig-ah adapter on Tindie today. If the zigpy-znp library supports ZGP then we can assume that zig-a-zig-ah adapter will soon be compatible with ZGP in Home Assistant and Jeedom. News of ZGP support with zig-a-zig-ah adapter will probably mean that Electrolama/omerk will sell more adapters on Tindie. If however zigpy only get support for ZGP with ConBee and Silicon Labs dongles then we can assume that at least some potential customers will instead buy those because they have better support, instead of buying zig-a-zig-ah adapter.

So in my opinion it does not to ask for a small hardware donation on behalf of a developer than is working on something like this.

PS: You should know that Electrolama/omerk has already donated zzh hardware donles to other zigpy-znp developers which directly or indirectly have lead to it becoming one of the best radio libraries for zigpy (which is used for Zigbee in Home Assistant), see https://github.com/electrolama/zig-a-zig-ah/issues/5

PPS: Disclaimer; I am just a fan of the zigpy project, I already own both a ConBee and a Silicon Labs dongle so have myself no personal gains doirectly from zigpy-znp getting ZGP support, but  I believe that ZGP support for all zigpy compatible hardware will indirectly benifit the whole community in the long-term as better Zigbee support in open source home automation software means more users which in turn normally leads more competition = less expensive devices = more developers = better products for all.

omerk, 2021-01-22:
Hi all,

To support the open-source home automation development community, I am happy to send boards to active developers of open-source home automation projects, costs covered by the Electrolama operation. Don't have the bandwidth to monitor Github issues spread across repos though so please get in touch (support@electrolama.com) with a link and a summary of your project and stock levels allowing I will ship you a board or two, or prototypes of upcoming projects.

Closed 2021-01-22.

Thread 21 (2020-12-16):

Failed to probe ZNP radio

Zaakupendrak, 2020-12-16:
Hi.

I got problem to create zigbee integration with zzh! under Home Assistant.
**HA image**: raspberrypi4-64-homeassistant:2020.12.0
**Platform**: Debian 10
**stick**: zzh!
**connection_type**: wire

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

```
root@rpi4-20201112:~# docker logs homeassistant
2020-12-16 10:28:43 WARNING (MainThread) [zigpy_zigate.api] No response to command 0x0002
2020-12-16 10:28:43 WARNING (MainThread) [zigpy_zigate.api] Retry command 0x0002
2020-12-16 10:28:46 WARNING (MainThread) [zigpy_xbee.api] at: No response to AP command
2020-12-16 10:28:47 WARNING (MainThread) [zigpy_cc.api] No response for: SRSP SYS version {}
2020-12-16 10:29:39 WARNING (MainThread) [zigpy_znp.zigbee.application] Failed to probe ZNP radio with config {'path': '/dev/serial/by-id/usb-1a86_USB_Serial-if00-port0', 'baudrate': 115200, 'flow_control': None}
Traceback (most recent call last):
  File "/usr/local/lib/python3.8/site-packages/zigpy_znp/zigbee/application.py", line 167, in probe
    await znp.connect()
  File "/usr/local/lib/python3.8/site-packages/zigpy_znp/api.py", line 234, in connect
    self._version = await self.request(c.SYS.Version.Req())
  File "/usr/local/lib/python3.8/site-packages/zigpy_znp/api.py", line 507, in request
    response = await response_future
asyncio.exceptions.CancelledError
During handling of the above exception, another exception occurred:
Traceback (most recent call last):
  File "/usr/local/lib/python3.8/site-packages/zigpy_znp/zigbee/application.py", line 167, in probe
    await znp.connect()
  File "/usr/local/lib/python3.8/site-packages/async_timeout/__init__.py", line 55, in __aexit__
    self._do_exit(exc_type)
  File "/usr/local/lib/python3.8/site-packages/async_timeout/__init__.py", line 92, in _do_exit
    raise asyncio.TimeoutError
asyncio.exceptions.TimeoutError
```

```
root@rpi4-20201112:~# docker ps
CONTAINER ID   IMAGE                                                   COMMAND                  CREATED          STATUS          PORTS                  NAMES
cc4c253552c9   homeassistant/raspberrypi4-64-homeassistant:2020.12.0   "/init"                  13 minutes ago   Up 13 minutes                          homeassistant
ee0bb0f6fe52   homeassistant/aarch64-hassio-multicast:3                "/init"                  13 minutes ago   Up 13 minutes                          hassio_multicast
cbbc7d439c70   homeassistant/aarch64-hassio-observer:2020.10.1         "/init"                  13 minutes ago   Up 13 minutes   0.0.0.0:4357->80/tcp   hassio_observer
c61debfb4211   homeassistant/aarch64-hassio-cli:2020.11.1              "/init /bin/bash -c …"   13 minutes ago   Up 13 minutes                          hassio_cli
26ded078ee16   homeassistant/aarch64-hassio-audio:17                   "/init"                  13 minutes ago   Up 13 minutes                          hassio_audio
fba6e4c7b005   homeassistant/aarch64-hassio-dns:2020.11.0              "/init"                  14 minutes ago   Up 14 minutes                          hassio_dns
5d250adf5551   homeassistant/aarch64-hassio-supervisor                 "/init"                  14 minutes ago   Up 14 minutes                          hassio_supervisor
```

```
pi@rpi4-20201112:~$ dmesg | grep -A 5 -B 5 341
[    9.339521] cfg80211: Loaded X.509 cert 'sforshee: 00b28ddf47aef9cea7'
[    9.346715] usbhid: USB HID core driver
[    9.365962] input: HOLDCHIP USB Gaming Keyboard as /devices/platform/scb/fd500000.pcie/pci0000:00/0000:00:00.0/0000:01:00.0/usb1/1-1/1-1.1/1-1.1:1.0/0003:04D9:0024.0001/input/input0
[    9.372458] platform regulatory.0: firmware: failed to load regulatory.db (-2)
[    9.395476] firmware_class: See https://wiki.debian.org/Firmware for information about missing firmware
[    9.397257] usbcore: registered new interface driver ch341
[    9.407699] platform regulatory.0: Direct firmware load for regulatory.db failed with error -2
[    9.417950] usbserial: USB Serial support registered for ch341-uart
[    9.419898] videodev: Linux video capture interface: v2.00
[    9.427286] cfg80211: failed to load regulatory.db
[    9.464429] hid-generic 0003:04D9:0024.0001: input,hidraw0: USB HID v1.10 Keyboard [HOLDCHIP USB Gaming Keyboard] on usb-0000:01:00.0-1.1/input0
[    9.471746] brcmfmac: brcmf_fw_alloc_request: using brcm/brcmfmac43455-sdio for chip BCM4345/6
[    9.492706] usbcore: registered new interface driver brcmfmac
[    9.494774] ch341 1-1.4:1.0: ch341-uart converter detected
[    9.495750] input: HOLDCHIP USB Gaming Keyboard System Control as /devices/platform/scb/fd500000.pcie/pci0000:00/0000:00:00.0/0000:01:00.0/usb1/1-1/1-1.1/1-1.1:1.1/0003:04D9:0024.0002/input/input1
[    9.532405] brcmfmac mmc0:0001:1: firmware: direct-loading firmware brcm/brcmfmac43455-sdio.bin
[    9.539173] usb 1-1.4: ch341-uart converter now attached to ttyUSB0
[    9.554597] input: HOLDCHIP USB Gaming Keyboard Consumer Control as /devices/platform/scb/fd500000.pcie/pci0000:00/0000:00:00.0/0000:01:00.0/usb1/1-1/1-1.1/1-1.1:1.1/0003:04D9:0024.0002/input/input2
[    9.575740] brcmfmac mmc0:0001:1: firmware: direct-loading firmware brcm/brcmfmac43455-sdio.raspberrypi,4-model-b.txt
[    9.588074] snd_bcm2835: module is from the staging directory, the quality is unknown, you have been warned.
[    9.605654] bcm2835_v4l2: module is from the staging directory, the quality is unknown, you have been warned.
[    9.605659] input: HOLDCHIP USB Gaming Keyboard as /devices/platform/scb/fd500000.pcie/pci0000:00/0000:00:00.0/0000:01:00.0/usb1/1-1/1-1.1/1-1.1:1.1/0003:04D9:0024.0002/input/input3
--
[  995.836734] IPv6: ADDRCONF(NETDEV_CHANGE): veth19e4479: link becomes ready
[  995.849219] hassio: port 5(veth19e4479) entered blocking state
[  995.860442] hassio: port 5(veth19e4479) entered forwarding state
[ 1013.847766] udevd[190]: starting version 3.2.9
[ 1013.859926] udevd[191]: starting eudev-3.2.9
[ 1093.394825] ch341-uart ttyUSB0: usb_serial_generic_read_bulk_callback - urb stopped: -32
[ 1093.409063] ch341-uart ttyUSB0: usb_serial_generic_read_bulk_callback - urb stopped: -32
[ 1093.529300] usb 1-1.4: USB disconnect, device number 4
[ 1093.539899] usb 1-1.4: ch341_read_int_callback - usb_submit_urb failed: -19
[ 1093.552792] usb 1-1.4: failed to send control message: -19
[ 1093.564326] ch341-uart ttyUSB0: ch341-uart converter now disconnected from ttyUSB0
[ 1093.575456] ch341 1-1.4:1.0: device disconnected
[ 1097.336993] usb 1-1.3: new full-speed USB device number 5 using xhci_hcd
[ 1097.455084] usb 1-1.3: New USB device found, idVendor=1a86, idProduct=7523, bcdDevice= 2.64
[ 1097.469001] usb 1-1.3: New USB device strings: Mfr=0, Product=2, SerialNumber=0
[ 1097.479738] usb 1-1.3: Product: USB Serial
[ 1097.493797] ch341 1-1.3:1.0: ch341-uart converter detected
[ 1097.508005] usb 1-1.3: ch341-uart converter now attached to ttyUSB0
```

Changing port/repluging/restarting RPI does not help.

Hedda, 2021-01-13:
@Zaakupendrak if this was an issue with ZHA in Home Assistant or the zigpy-znp library then you might have been better of posting to https://github.com/home-assistant/core/ and/or https://github.com/zigpy/zigpy-znp however I am wondering if you have really managed to correctly flash an application firmware the adapter properly with Z-Stack 3 Zigbee stack application firmware as zzh does ship pre-flashed with a Zigbee coordinator firmware.

https://electrolama.com/projects/zig-a-zig-ah/

"**_Please keep in mind that zzh is a general purpose development board and as such, it is shipped "blank" with no code on the wireless microcontroller. You will need to program it before it does anything meaningful._** _Given the application dependent nature of this board, limited after-sales support can be provided for Tindie purchases (For example: we can help you program this board but can't fix your Zigbee network range issues or offer specific software support)._"

Suggest that you install drivers, enter bootloader mode and try using BSL again to flash correct firmware Z-Stack coordinator firmware from @Koenkk's firmware repository.

https://github.com/Koenkk/Z-Stack-firmware/tree/master/coordinator/Z-Stack_3.x.0/bin

"**_Download the Z-Stack coordinator firmware from @Koenkk's firmware repository. The firmware you'll need can be found under coordinator/Z-Stack_3.x.0/bin/CC26X2R1_<date>.zip, **_as of writing the latest version available is CC26X2R1_20200805.zip. Download and extract this and follow the "Flashing using BSL" instructions to burn this on your zzh_**_**."

omerk, 2021-01-22:
@Zaakupendrak hope you were able to solve your problem.  I don't monitor Github issues for support, please send an email to support@electrolama.com instead if you'd like some help (it does seem like it is either a firmware or a ZNP configuration issue there).

Zaakupendrak, 2021-01-22:
Hi,

The problem was that I didn’t flash stick. Once I did, everything seems
working :)

Thank you for your attention.

W dniu pt., 22.01.2021 o 12:21 Omer Kilic <notifications@github.com>
napisał(a):

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
--
Pozdrawiam,
Szymon Jakubowski

Hedda, 2021-01-22:
> Hi, The problem was that I didn’t flash stick. Once I did, everything seems working :)

Suspected it was so. Suggested in https://github.com/electrolama/zig-a-zig-ah/issues that future zzh sticks shipped pre-flashed.

Closed 2021-01-22.

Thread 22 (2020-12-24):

Timeout waiting for ACK/NACK after 'Synch (0x55 0x55)'

seb-koch, 2020-12-24:
Hi,

i am seeking help as i am running out of ideas. I ordered two zzh and i am unable to flash the koenk firmware to either of them. I tried several procedurs, including flashing a blink.bin to the device, erasing flash and such. I followed all the instructions and always unplugged the stick, held the bsl button, plugged it back in (waited for 3, 5 or 10 seconds) and tried flashing to it. None of it worked so i guess i am doing smth really wrong here or i am missing an important step.

Here is the output after plugging it back in with BSL (blinking stopped so the blink.bin wasn't loaded i guess).
```
sebo@esmombibi:~/download/cc2538-bsl-master$ sudo ./cc2538-bsl.py -p /dev/ttyUSB0 -evw CC26X2R1_20201026.hex
Opening port /dev/ttyUSB0, baud 500000
Reading data from CC26X2R1_20201026.hex
Your firmware looks like an Intel Hex file
Connecting to target...
ERROR: device reports readiness to read but returned no data (device disconnected or multiple access on port?)
sebo@esmombibi:~/download/cc2538-bsl-master$ sudo ./cc2538-bsl.py -p /dev/ttyUSB0 -evw CC26X2R1_20201026.hex
Opening port /dev/ttyUSB0, baud 500000
Reading data from CC26X2R1_20201026.hex
Your firmware looks like an Intel Hex file
Connecting to target...
ERROR: Timeout waiting for ACK/NACK after 'Synch (0x55 0x55)'
```

And here is the dmesg showing it was detected.
```
[   92.467388] ch341 1-1:1.0: ch341-uart converter detected
[   92.467772] usb 1-1: ch341-uart converter now attached to ttyUSB0
[  146.754652] usb 1-1: USB disconnect, device number 6
[  146.754836] usb 1-1: failed to send control message: -19
[  146.754980] ch341-uart ttyUSB0: ch341-uart converter now disconnected from ttyUSB0
[  146.754995] ch341 1-1:1.0: device disconnected
[  150.243591] usb 1-1: new full-speed USB device number 7 using xhci_hcd
[  150.392701] usb 1-1: New USB device found, idVendor=1a86, idProduct=7523
[  150.392704] usb 1-1: New USB device strings: Mfr=0, Product=2, SerialNumber=0
[  150.392706] usb 1-1: Product: USB Serial
[  150.393341] ch341 1-1:1.0: ch341-uart converter detected
[  150.393695] usb 1-1: ch341-uart converter now attached to ttyUSB0
```

Thanks in advance.
Merry Christmas and enjoy the holidays.
Seb

seb-koch, 2021-01-07:
I found the root cause. It seems like a `sudo` doesn't give enough privileges to communicate with the interface. Once switched into root via `sudo su`it worked like a charm. You can close the issue and i suggest to change the documentation and state clearly that full root is necessary.
The docs aren't in here afaik, i'd be happy to alter the docs via a PR if this helps?

RaymondMouthaan, 2021-02-05:
@seb-koch,

I am facing the same issue on one of my CC2652R usb sticks. However `sudo su` didn't work for me :(

While pressing and holding the small button and putting the stick in the USB port, the led remains blinking. Then I run the command below with the given error:

```
root# ./cc2538-bsl.py -p /dev/ttyUSB0 -evw blink.bin
Opening port /dev/ttyUSB0, baud 500000
Reading data from blink.bin
Cannot auto-detect firmware filetype: Assuming .bin
Connecting to target...
ERROR: Timeout waiting for ACK/NACK after 'Synch (0x55 0x55)'
```

In this case I am just flashing the blink.bin, but same error occurs when flashing the .hex

Looks like the stick doesn't go to flash mode? Any idea how to fix this?

Thanks in advance,
Ray

VincentSC, 2021-12-11:
FYI: for me the `sudo su` trick *did* work.

zen2, 2021-12-11:
I think you can simply become root first:

`# sudo -i`  [enter the user password]
or
`# su -`                     [enter the root password]

VincentSC, 2021-12-11:
It is not about becoming root, but that the python-script does not work by running the script as root.

zen2, 2021-12-13:
> It is not about becoming root, but that the python-script does not work by running the script as root.

The script is working perfectly as root. It's not working when the script is launched via sudo.
In fact sudo restrict root environment by default so technically the script is launched as root but don't have access to everything that real user root can access. Than can be relaxed by sudo configuration or simply by becoming root with a full root environment like a real login result. That's the purpose of both command I posted.
These commands can be completed with '-c' option to add a command to be launched in resulting login shell.

VincentSC, 2021-12-13:
I meant "running as sudo" - matter of speak. It's a documentation problem then.

ovizii, 2022-06-09:
I've been scratching my head the whole time as SONOFF Zigbee 3.0 USB Dongle Plus does not have a button. I then figured out I'd have to open its metal case to get to the buttons?

In the picture by itead there are two buttons:
- boot button
- reset button

I assume you're all talking about the boot button?

Closed 2021-01-07.

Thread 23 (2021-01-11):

Enhancement : Add RF amplifier CC2592

wojciechczyz, 2021-01-11:
Are you considering creating version with amplifier such as CC2592?

Hedda, 2021-01-13:
CC2592 + CC2652R works but such solution would be more expensive than using a CC2652P instead of CC2652R + CC2592. Read:

https://e2e.ti.com/support/wireless-connectivity/bluetooth/f/538/t/965346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

FYI, while "zzh-p" is not yet available the design use CC2652P instead which does have an internal RF PA (power-amplifier) integrated:

https://electrolama.com/projects/zig-a-zig-ah/#Flavours

 **"_zzh-p is the experimental version with CC2652P (built-in PA). Shares most of the same design with zzh except for the RF parts and will fit in a slightly larger case. It is a work in progress, sign up to the Electrolama mailing list to be notified of project updates and when kits/assembled units go on sale. A sneak peek:_"**

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

https://electrolama.com/projects/zig-a-zig-ah/#aside-ti-part-numbers

**_"CC2652P = CC2652R with a built-in RF PA. Not pin or firmware compatible with CC2652R/CC2652RB. zzh-p will use this._**"

omerk, 2021-01-22:
Thanks for the suggestion @wojciechczyz, as Hedda mentioned there is a new design (two, in fact) based on CC2652P that does have a PA built-in. Keep an eye on the repo/website (electrolama.com) 🙂

Closed 2021-01-22.

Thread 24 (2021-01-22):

zzh-p stick based CC2652P?

Hedda, 2021-01-22:
Noticed that Koenkk is now also hosting Z-Stack 3 coordinator firmware for "Electrolama zzhp" and "Electrolama zzhp-lite":

https://github.com/Koenkk/Z-Stack-firmware/tree/develop/coordinator/Z-Stack_3.x.0/bin

@omerk Any status updates on Electrolama's "zzh-p" and "zzhp-lite" products based on CC2652P?

https://electrolama.com/projects/zig-a-zig-ah/#Flavours

"**_zzh-p is the experimental version with CC2652P (built-in PA). Shares most of the same design with zzh except for the RF parts and will fit in a slightly larger case. It is a work in progress, sign up to the Electrolama mailing list to be notified of project updates and when kits/assembled units go on sale. A sneak peek:_**"

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

omerk, 2021-01-22:
Hi @Hedda,

There will be two versions zzh with CC2652P: zzhp and zzhp-lite. Both will use the same firmware, zzhp-lite will be module-based (PCB antenna) and zzhp will be a custom board similar to the first draft screenshot you linked above (external antenna). I've also managed to squeeze in a few more goodies in zzhp and will be updating the website soon.

Release date not set yet but it's _very_ soon.

Happy to send you a prototype as a thank you for your contributions to the documentation and keeping an eye on these issues, please drop me an email (support @ electrolama.com) with your address 🙂

Hedda, 2021-03-24:
> Happy to send you a prototype as a thank you for your contributions to the documentation and keeping an eye on these issues, please drop me an email (support @ electrolama.com) with your address 🙂

Hi @omerk I can wait, but maybe you consider sending one to @zoic21 and/or @sarakha63 to test with https://github.com/zigpy/zigpy/pull/656 (ZGP)?

Closed 2021-01-22.

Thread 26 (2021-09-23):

[SUGGESTION] Switch to USB-to-UART bridge chip with programmable EEPROM so can add custom "Product Description String" string as unique identifier

Hedda, 2021-09-23:
@omerk Please consider switching design to other USB-to-Serial converter chip with its own writable EEPROM as hardware feature.

This would allow you to add your own custom "Product Description String" as a unique identifier for it via the USB interface, and the reason for wanting a unique identifier via the USB interface is in order to enable the possibility for it to support automatic USB discovery of Zigbee USB adapters.

The whole point of this is to make it possible for developers to make the initial installation of Zigbee solution plug-and-play friendly and easier for different home automation software to automatically USB discover and initiate a setup without end-user interactions.

Support for USB discovery was recently added to Home Assistant OS (formerly HASSIO) and the ZHA integration for it, see here:

https://community.home-assistant.io/t/unique-friendly-name-description-for-automatic-zigbee-usb-adapter-discovery-in-home-assistant-zha-using-dongle-vendor-product-i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

That unique customized USB description string could be something like ex.; "_**Electrolama zig-a-zig-ah (zzh) CC2652R Zigbee stick version 2 hardware revision 2.0.0**_".

The unique "description" string for each USB adapter can then be added to HA via a PR like this -> https://github.com/home-assistant/core/pull/56201

As I understand it, cheaper CH340 series (example CH340C and CH340E) by WCH which unfortunately does not support this feature.

UPDATE! It has now been confirmed that the CH340B variant does have an EEPROM that support "Product Description String", etc.

http://www.wch-ic.com/products/CH340.html

I understand that more expensive chips like FT231 chips by FTDI and CP210x chips by Silicon Labs / Silabs do support this feature:

https://ftdichip.com/products/ft231xs/
https://ftdichip.com/products/ft231xq/

FT231X/FT231XS: "**_Key Hardware Features_**" "**_Fully integrated 2048 byte EEPROM for storing device descriptors and CBUS I/O configuration._**"

https://www.silabs.com/interface/usb-bridges/classic/device.cp2102
https://www.silabs.com/interface/usb-bridges/classic/device.cp2104
https://www.silabs.com/developers/usb-to-uart-bridge-vcp-drivers
https://www.silabs.com/documents/public/data-sheets/cp2102n-datasheet.pdf
https://www.silabs.com/documents/public/application-notes/an197.pdf
https://www.silabs.com/documents/public/application-notes/an978-cp210x-usb-to-uart-api-specification.pdf
https://www.silabs.com/documents/public/application-notes/AN571.pdf

"**_The CP2102N devices have the following features_**" "**_Internal 960-byte programmable ROM for vendor ID, product ID, serial number, power descriptor, release number, and product description strings_**"

"**_The CP2102N includes an internal electrically erasable programmable read-only memory (EEPROM). This memory may be used to customize the USB Vendor ID (VID), Product ID (PID), Product Description String, Power Descriptor, Device Release Number and Device Serial Number as desired for OEM applications. If the EEPROM is not programmed with OEM data, the default configuration data shown in the table below is used._**"

"**_Product String The Product String is an optional string that describes the product. It is limited to 126 characters._**"

PS: I understand that a bonus feature in of chips like FT231 and CP210x is to add the ability to allow users to auto-reset and put the device in bootloader mode via the DTR/RTS pins exposed will enable much easier firmware upgrades for the end-users as they will no longer need to press any buttons to enter bootloader mode, and then bootloader mode could be activated via software from the firmware flasher program software which could make the OTW (Over-The-Wire) firmware upgrade procedure more user-friendly.

omerk, 2021-10-08:
Hi @Hedda,

zzhp and zzh2 both use FT231X and will come with customised "Manufacturer" and "Product Description" strings. zzh will keep CH340E.

Closing this issue.

Closed 2021-10-08.

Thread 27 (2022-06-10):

[REQUEST] OpenThread Border Router (OTBR) RCP firmware for CC2652R based Electrolama zzh (zig-a-zig-ah) adapter?

Hedda, 2022-06-10:
@omerk Can you please consider providing an OpenThread Border Router (OTBR) RCP firmware for this Texas Instruments CC2652 based adapter that is compatible with the "OpenThread Border Router Add-on" that Home Assistant developer agners (Nabu Casa employee Stefan Agner) is currently developing?

https://github.com/home-assistant/addons-development/tree/master/openthread_border_router

https://github.com/agners

https://community.home-assistant.io/u/agners/summary

The main reason for this request is that such an RPC firmware with OTBR (OpenThread Border Router) support will make your adapter will be compatible with upcoming Thread based "Matter" (Project CHIP / Connected Home over IP) devices if used in Home Assistant with their other add-ons for the that is also in development.

https://github.com/home-assistant/addons-development/tree/master/chip_controller_repl

https://github.com/home-assistant/addons-development/tree/master/chip_tool

https://github.com/project-chip/connectedhomeip

https://buildwithmatter.com

https://csa-iot.org/all-solutions/matter/

Note that so far agners has only worked with Silicon Labs based adapter with OpenThread RPC firmware for Thread based Matter (as well as ESP32-C3 based devkit for Matter over WiFi) and that is only because it is a Silabs EFR32MG21 chip based adapter that will ship inside the official Home Assistant Yellow (formerly Home Assistant Amber) hardware:

https://github.com/zigpy/zigpy/discussions/894

https://github.com/home-assistant/addons-development/tree/master/silabs-multiprotocol

https://www.home-assistant.io/blog/2021/09/13/home-assistant-yellow/

https://www.crowdsupply.com/nabu-casa/home-assistant-yellow

PS: By the way, you might be interesting in the the "Matter" workshop that Home Assistant is holding on the 15th of June even if they are in that specific workshop will not use a Thread based controller or devices and instead use a WiFi (+ Bluetooth) based "Matter" devices:

https://www.home-assistant.io/blog/2022/05/29/matter-in-home-assistant-workshop-announcement/

https://www.youtube.com/watch?v=9fOHBl5w0_k

https://community.home-assistant.io/t/matter-in-home-assistant-workshop-announcement/426129/

Hedda, 2022-06-22:
@omerk If have time please also see this and if possible contribute to discussion too -> https://github.com/home-assistant/addons-development/issues/38

Hedda, 2022-09-27:
@omerk FYI, missed that tube0013 posted on Twitter that be uploaded OpenThread RCP firmware images for the CC2652P (TubesZB devices) CC2652R (zzh!) that could be used for development and testing as he confirmed those working with agners OTBR addon from addons-development so that could be of interest for those early adopters interested in Thread/Matter support inside Home Assistant:

https://twitter.com/TubesZb/status/1552823766136373251

https://github.com/tube0013/tube_gateways/tree/main/openthread_boarder_router_fw

Again more discussion about CC2652 RPC firmware support for OpenThread here:

https://github.com/home-assistant/addons-development/issues/38

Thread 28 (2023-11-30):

[REQUEST NEWER HARDWARE] CC2674 (CC2674P/CC2674R) and CC1354P (CC1354P) Zigbee Coordinator and Zigbee Router adapters?

Hedda, 2023-11-30:
Will you consider making CC2674/CC2674P/CC2674R and/or CC1354/CC1354P Zigbee adapters for developers and early adopters?

Check out this developer discussion in Koenkk's Z-Stack firmware repository -> https://github.com/Koenkk/Z-Stack-firmware/discussions/476

There is no community firmware from Koenkk yet but that is probably partially because no one made a CC2674 or CC1354 adapter yet.

Chicken or the egg, what comes first, early prototype adapters that Koenkk can test or firmware built in the blind?

FYI, E72-2G4M20S1C (CC2674P10) radio module from Ebyte/Cdebyte is already available for prototyping and first-to-market devices:

https://www.cdebyte.com/products/E72-2G4M20S1C

According to [LSagiroglu](https://github.com/LSagiroglu) this new CC2674P10 based module is is pin to pin compatible with their CC2652P based module:

https://www.cdebyte.com/products/E72-2G4M20S1E

PS: No news so far from RFstar if they are working on CC2674P or CC1354P radio modules yet.

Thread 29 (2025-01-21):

CC2652R won't go into BSL mode

mrreview, 2025-01-21:
I've been trying to connect the device into a USB slot in BSL mode and no matter what, the device won't go into BSL. Windows detect it without any problems

I've followed the instructions:

`It is imperative that you press and hold the BSL pushbutton before plugging it in to the host and release it after a few seconds. If you don't follow this, your stick will not enter BSL mode and flashing will fail.`

But this time I don't know why it can't enter in BSL mode, long time ago I did it without any problems.

Thank you.

mrreview, 2025-01-21:
Nevermind, the device in fact it was in bsl mode, the error in ti flaseher was nothing to do with not in bsl mode, followed this and did the trick
https://github.com/Koenkk/Z-Stack-firmware/issues/397#issuecomment-1963087030

Closed 2025-01-21.

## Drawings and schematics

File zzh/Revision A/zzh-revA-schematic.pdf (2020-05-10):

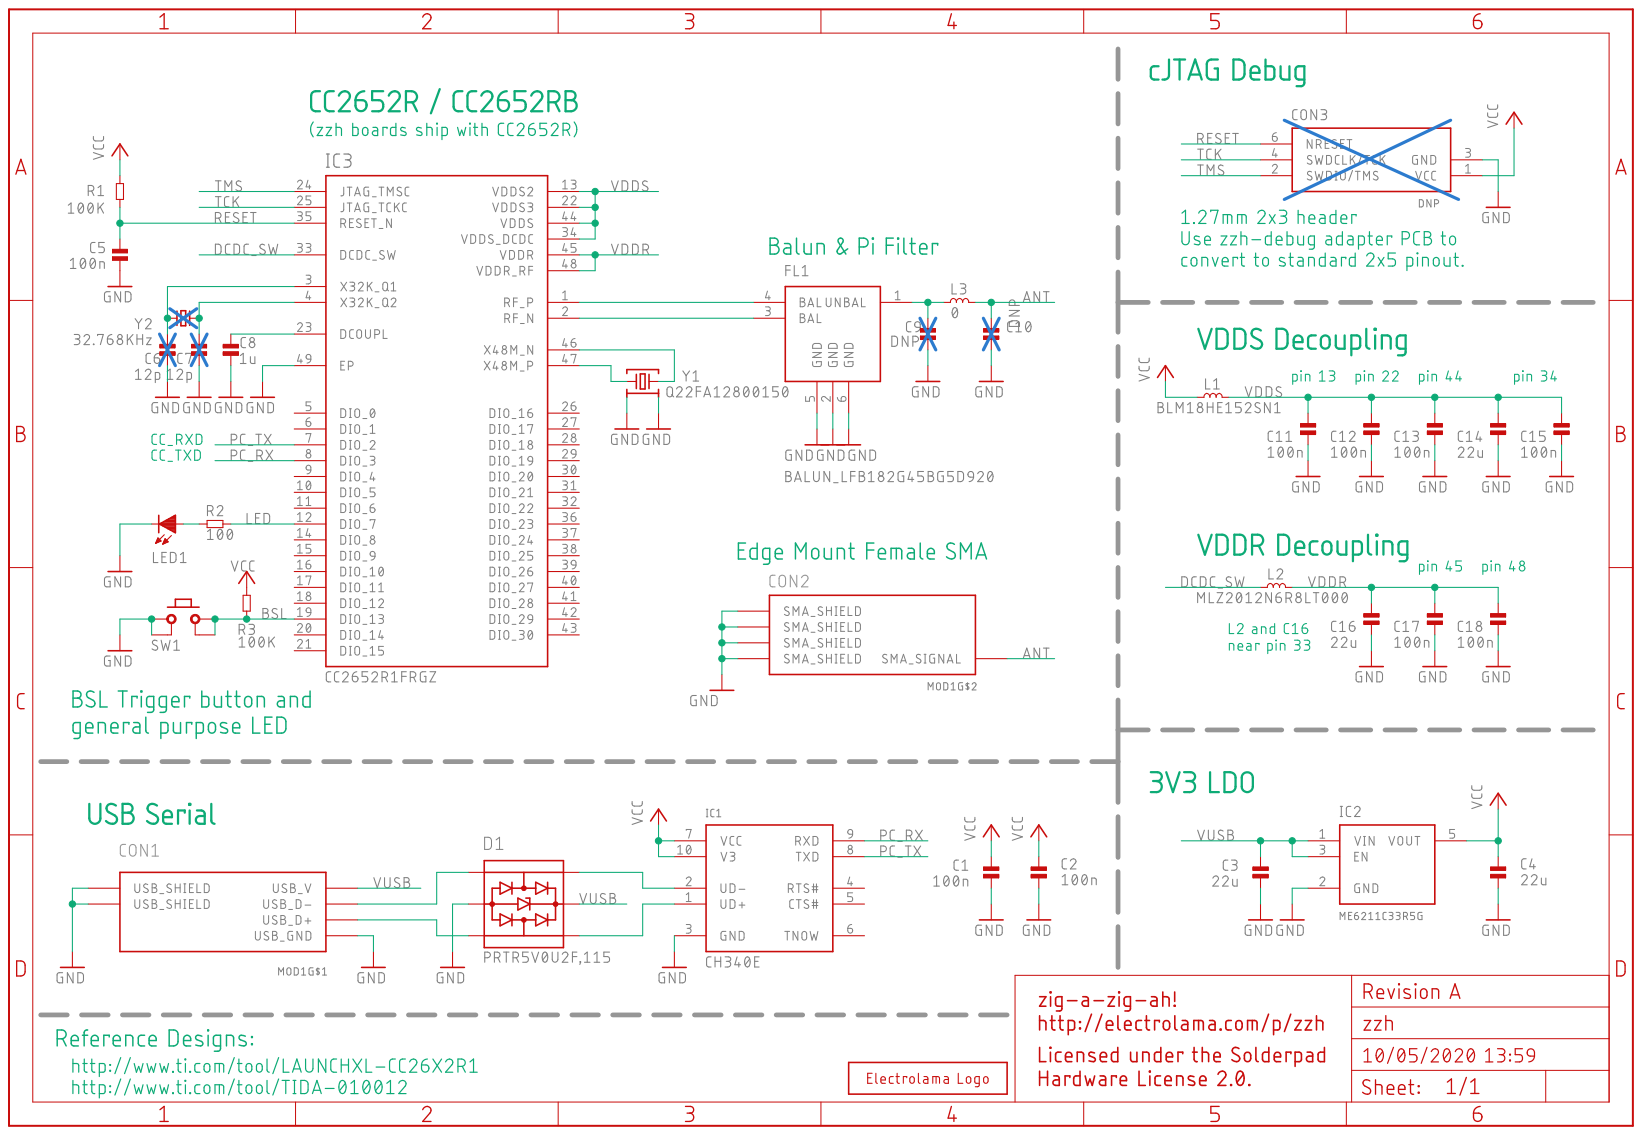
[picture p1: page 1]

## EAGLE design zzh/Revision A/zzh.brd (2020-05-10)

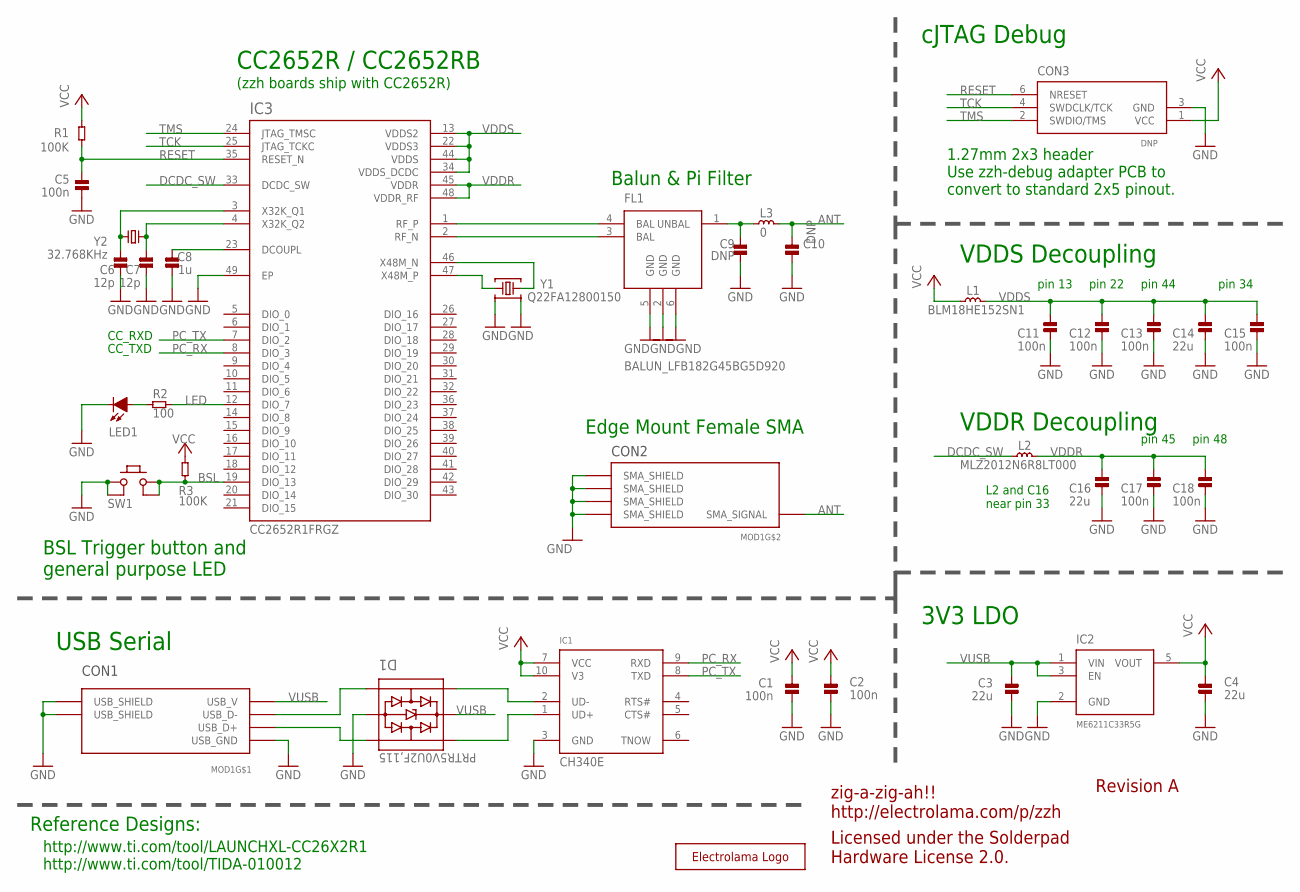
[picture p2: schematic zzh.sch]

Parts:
C1, C2, C5, C11, C12, C13, C15, C17, C18: 100n; _PKG_C_0402
C3, C4, C14, C16: 22u; _PKG_C_0805
C6, C7: 12p; _PKG_C_0402
C8: 1u; _PKG_C_0402
C9, C10: DNP; _PKG_C_0402
CON3: DNP; DEBUG_CORTEX_5PIN
D1: PRTR5V0U2F,115; _PKG_SOT886_JEDEC-MO-252
FL1: BALUN_LFB182G45BG5D920; LFB182G45BG5D920
IC1: CH340E; _PKG_MSOP10_TI-DGS10
IC2: ME6211C33R5G; SOT65P212X110-5N
IC3: CC2652R1FRGZ; QFN50P700X700X100-49N
L1: BLM18HE152SN1; _PKG_L_0603
L2: MLZ2012N6R8LT000; _PKG_C_0805
L3: 0; _PKG_L_0402
LED1: LED-0603; _PKG_LED_0603
MOD1: ZZH_MODULE
R1, R3: 100K; _PKG_C_0402
R2: 100; _PKG_C_0402
SW1: K2-1177SW-D4DW-06
U$5: LOGO-ELECTROLAMA; ELECTROLAMA
Y1: Q22FA12800150; XTAL-4P-2016
Y2: 32.768KHz; XTAL-2P-3215

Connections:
ANT: C10.2, L3.2, MOD1.SMA_SIGNAL
BSL: IC3.19 (DIO_13), R3.2, SW1.3 (2_1), SW1.4 (2_2)
DCDC_SW: IC3.33 (DCDC_SW), L2.1
DCOUPL: C8.2, IC3.23 (DCOUPL)
GND: C1.1, C2.1, C3.2, C4.2, C5.1, C6.1, C7.1, C8.1, C9.1, C10.1, C11.2, C12.2, C13.2, C14.2, C15.2, C16.2, C17.2, C18.2, CON3.3 (GND), D1.2, FL1.2 (GND), FL1.5 (GND), FL1.6 (GND), IC1.3 (GND), IC2.2 (GND), IC3.49 (EP), LED1.C, MOD1.SMA_SHIELD_1 (SMA_SHIELD), MOD1.SMA_SHIELD_2 (SMA_SHIELD), MOD1.SMA_SHIELD_3 (SMA_SHIELD), MOD1.SMA_SHIELD_4 (SMA_SHIELD), MOD1.USB_GND, MOD1.USB_SHIELD_1 (USB_SHIELD), MOD1.USB_SHIELD_2 (USB_SHIELD), SW1.1 (1_1), SW1.2 (1_2), Y1.2, Y1.4
LED: IC3.12 (DIO_7), R2.1
unnamed: LED1.A, R2.2
PC_RX: IC1.9 (RXD), IC3.8 (DIO_3)
PC_TX: IC1.8 (TXD), IC3.7 (DIO_2)
RESET: C5.2, CON3.6 (NRESET), IC3.35 (RESET_N), R1.1
RF_N: FL1.3 (BAL), IC3.2 (RF_N)
RF_P: FL1.4 (BAL), IC3.1 (RF_P)
TCK: CON3.4 (SWDCLK/TCK), IC3.25 (JTAG_TCKC)
TMS: CON3.2 (SWDIO/TMS), IC3.24 (JTAG_TMSC)
UD+: D1.6, IC1.1 (UD+)
UD-: D1.4, IC1.2 (UD-)
UNBAL: C9.2, FL1.1 (UNBAL), L3.1
USB_D+: D1.1, MOD1.USB_D+
USB_D-: D1.3, MOD1.USB_D-
VCC: C1.2, C2.2, C4.1, CON3.1 (VCC), IC1.7 (VCC), IC1.10 (V3), IC2.5 (VOUT), L1.1, R1.2, R3.1
VDDR: C16.1, C17.1, C18.1, IC3.45 (VDDR), IC3.48 (VDDR_RF), L2.2
VDDS: C11.1, C12.1, C13.1, C14.1, C15.1, IC3.13 (VDDS2), IC3.22 (VDDS3), IC3.34 (VDDS_DCDC), IC3.44 (VDDS), L1.2
VUSB: C3.1, D1.5, IC2.1 (VIN), IC2.3 (EN), MOD1.USB_V
X32K_Q1: C6.2, IC3.3 (X32K_Q1), Y2.1
X32K_Q2: C7.2, IC3.4 (X32K_Q2), Y2.2
X48M_N: IC3.46 (X48M_N), Y1.3
X48M_P: IC3.47 (X48M_P), Y1.1

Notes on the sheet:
VDDS Decoupling
pin 13
pin 22
pin 44
pin 34
pin 45
pin 48
VDDR Decoupling
L2 and C16 near pin 33
zig-a-zig-ah!! http://electrolama.com/p/zzh
Revision A
CC_RXD
CC_TXD
cJTAG Debug
3V3 LDO
USB Serial
CC2652R / CC2652RB
Balun & Pi Filter
BSL Trigger button and general purpose LED
Reference Designs:
http://www.ti.com/tool/LAUNCHXL-CC26X2R1 http://www.ti.com/tool/TIDA-010012
Licensed under the Solderpad Hardware License 2.0.
1.27mm 2x3 header Use zzh-debug adapter PCB to convert to standard 2x5 pinout.
CON2
CON1
(zzh boards ship with CC2652R)
Edge Mount Female SMA

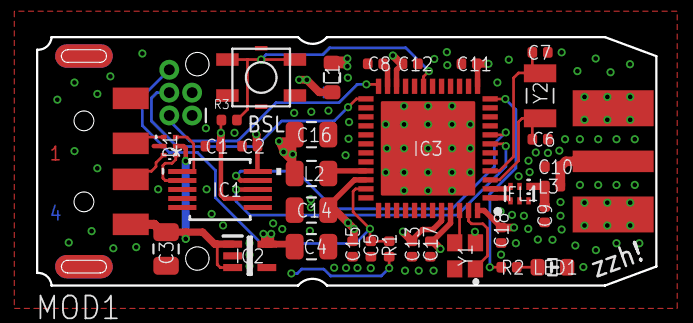
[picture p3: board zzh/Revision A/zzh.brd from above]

Board: 4 copper layers, 34.4 x 13.8 mm, 36 parts (1 on the bottom side), 27 nets.

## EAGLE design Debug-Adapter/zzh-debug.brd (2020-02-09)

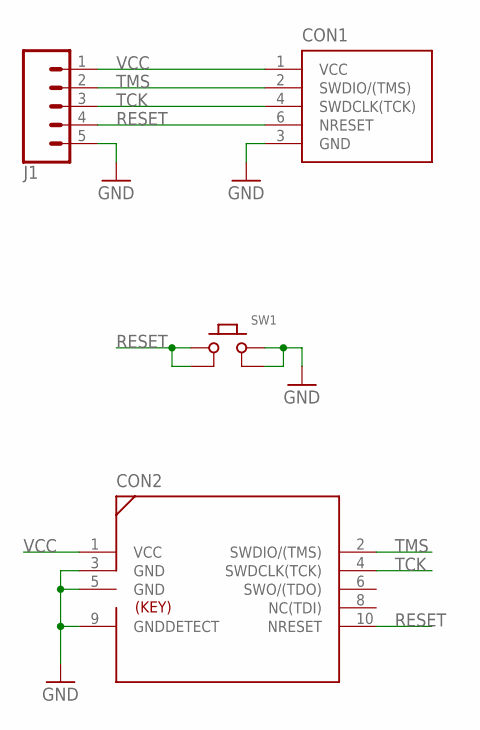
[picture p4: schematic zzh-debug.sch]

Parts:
CON1: DEBUG_CORTEX-SWD-5PIN-FEMALE6; SHENZHEN_2X3_1.27MM_TH_FEMALE
CON2: DEBUG_CORTEX-SWD-TH; SHENZHEN_2X5_1.27MM_TH_MALE_SHROUD
J1: CONN_05LOCK_LONGPADS; 1X05_LOCK_LONGPADS
SW1: PUSHBUTTON-K2-1177SW-D4DW-06; K2-1177SW-D4DW-06

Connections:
GND: CON1.3 (GND), CON2.3 (GND), CON2.5 (GND), CON2.9 (GNDDETECT), J1.5, SW1.3 (2_1), SW1.4 (2_2)
RESET: CON1.6 (NRESET), CON2.10 (NRESET), J1.4, SW1.1 (1_1), SW1.2 (1_2)
TCK: CON1.4 (SWDCLK(TCK)), CON2.4 (SWDCLK(TCK)), J1.3
TMS: CON1.2 (SWDIO/(TMS)), CON2.2 (SWDIO/(TMS)), J1.2
VCC: CON1.1 (VCC), CON2.1 (VCC), J1.1

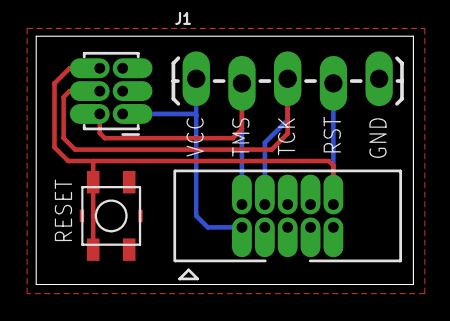
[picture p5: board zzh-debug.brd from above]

Board: 2 copper layers, 21.0 x 13.8 mm, 4 parts (0 on the bottom side), 5 nets.

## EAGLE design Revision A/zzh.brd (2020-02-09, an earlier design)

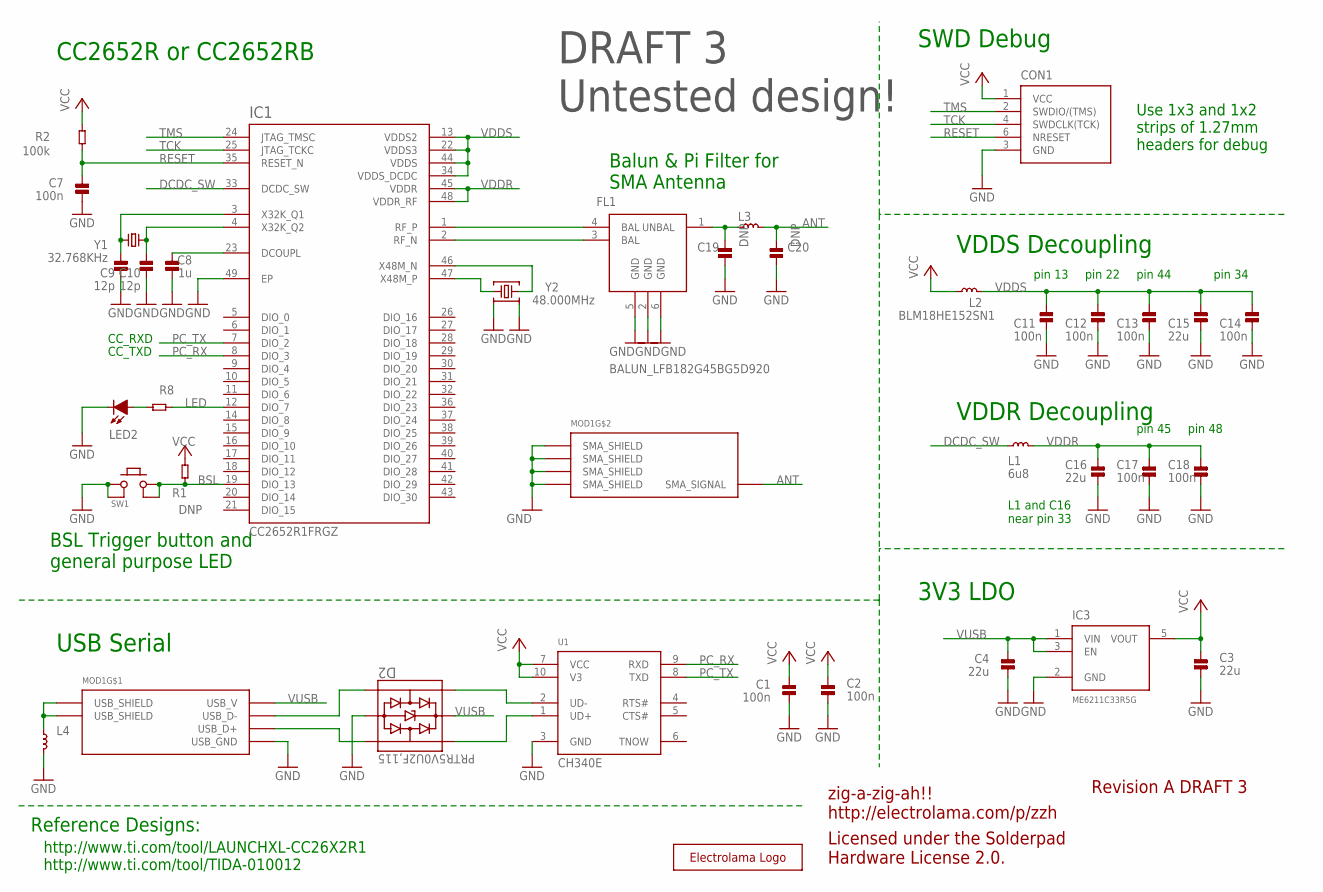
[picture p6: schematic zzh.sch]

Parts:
C1, C2, C7, C11, C12, C13, C14, C17, C18: 100n; _PKG_C_0402
C3, C4, C15, C16: 22u; _PKG_C_0805
C8: 1u; _PKG_C_0402
C9, C10: 12p; _PKG_C_0402
C19, C20: DNP; _PKG_C_0402
CON1: DEBUG_CORTEX-SWD-5PIN-CUT5; DEBUG_CORTEX_5PIN
D2: PRTR5V0U2F,115; _PKG_SOT886_JEDEC-MO-252
FL1: BALUN_LFB182G45BG5D920; LFB182G45BG5D920
IC1: CC2652R1FRGZ; QFN50P700X700X100-49N
IC3: ME6211C33R5G; SOT65P212X110-5N
L1: 6u8; _PKG_C_0805
L2: BLM18HE152SN1; _PKG_L_0603
L3, L4: INDUCTOR-0402; _PKG_L_0402
LED2: LED-0603; _PKG_LED_0603
MOD1: ZZH_MODULE
R1: DNP; _PKG_C_0402
R2: 100k; _PKG_C_0402
R8: RES-0402; _PKG_C_0402
SW1: K2-1177SW-D4DW-06
U1: CH340E; _PKG_MSOP10_TI-DGS10
U$5: LOGO-ELECTROLAMA; ELECTROLAMA
Y1: 32.768KHz; XTAL-2P-3215
Y2: 48.000MHz; XTAL-4P-2016

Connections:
ANT: C20.2, L3.2, MOD1.SMA_SIGNAL
BSL: IC1.19 (DIO_13), R1.2, SW1.3 (2_1), SW1.4 (2_2)
DCDC_SW: IC1.33 (DCDC_SW), L1.1
DCOUPL: C8.2, IC1.23 (DCOUPL)
GND: C1.1, C2.1, C3.2, C4.2, C7.1, C8.1, C9.1, C10.1, C11.2, C12.2, C13.2, C14.2, C15.2, C16.2, C17.2, C18.2, C19.1, C20.1, CON1.3 (GND), D2.2, FL1.2 (GND), FL1.5 (GND), FL1.6 (GND), IC1.49 (EP), IC3.2 (GND), L4.2, LED2.C, MOD1.SMA_SHIELD_1 (SMA_SHIELD), MOD1.SMA_SHIELD_2 (SMA_SHIELD), MOD1.SMA_SHIELD_3 (SMA_SHIELD), MOD1.SMA_SHIELD_4 (SMA_SHIELD), MOD1.USB_GND, SW1.1 (1_1), SW1.2 (1_2), U1.3 (GND), Y2.2, Y2.4
LED: IC1.12 (DIO_7), R8.1
unnamed: L4.1, MOD1.USB_SHIELD_1 (USB_SHIELD), MOD1.USB_SHIELD_2 (USB_SHIELD)
unnamed: LED2.A, R8.2
PC_RX: IC1.8 (DIO_3), U1.9 (RXD)
PC_TX: IC1.7 (DIO_2), U1.8 (TXD)
RESET: C7.2, CON1.6 (NRESET), IC1.35 (RESET_N), R2.1
RF_N: FL1.3 (BAL), IC1.2 (RF_N)
RF_P: FL1.4 (BAL), IC1.1 (RF_P)
TCK: CON1.4 (SWDCLK(TCK)), IC1.25 (JTAG_TCKC)
TMS: CON1.2 (SWDIO/(TMS)), IC1.24 (JTAG_TMSC)
UD+: D2.6, U1.1 (UD+)
UD-: D2.4, U1.2 (UD-)
UNBAL: C19.2, FL1.1 (UNBAL), L3.1
USB_D+: D2.1, MOD1.USB_D+
USB_D-: D2.3, MOD1.USB_D-
VCC: C1.2, C2.2, C3.1, CON1.1 (VCC), IC3.5 (VOUT), L2.1, R1.1, R2.2, U1.7 (VCC), U1.10 (V3)
VDDR: C16.1, C17.1, C18.1, IC1.45 (VDDR), IC1.48 (VDDR_RF), L1.2
VDDS: C11.1, C12.1, C13.1, C14.1, C15.1, IC1.13 (VDDS2), IC1.22 (VDDS3), IC1.34 (VDDS_DCDC), IC1.44 (VDDS), L2.2
VUSB: C4.1, D2.5, IC3.1 (VIN), IC3.3 (EN), MOD1.USB_V
X32K_Q1: C9.2, IC1.3 (X32K_Q1), Y1.1
X32K_Q2: C10.2, IC1.4 (X32K_Q2), Y1.2
X48M_N: IC1.46 (X48M_N), Y2.3
X48M_P: IC1.47 (X48M_P), Y2.1

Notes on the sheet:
VDDS Decoupling
pin 13
pin 22
pin 44
pin 34
pin 45
pin 48
VDDR Decoupling
L1 and C16 near pin 33
zig-a-zig-ah!! http://electrolama.com/p/zzh
Revision A DRAFT 3
CC_RXD
CC_TXD
SWD Debug
3V3 LDO
USB Serial
CC2652R or CC2652RB
Balun & Pi Filter for SMA Antenna
BSL Trigger button and general purpose LED
Reference Designs:
http://www.ti.com/tool/LAUNCHXL-CC26X2R1 http://www.ti.com/tool/TIDA-010012
Licensed under the Solderpad Hardware License 2.0.
Use 1x3 and 1x2 strips of 1.27mm headers for debug
DRAFT 3 Untested design!

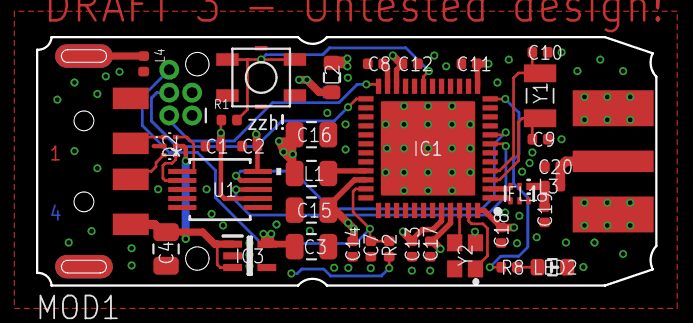
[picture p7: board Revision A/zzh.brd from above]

Board: 4 copper layers, 34.4 x 13.8 mm, 37 parts (1 on the bottom side), 28 nets.

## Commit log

2020-02-01 Revision A, Draft 1 check-in
    [zzh.brd, zzh.sch]
2020-02-03 Revision A, Draft 2 check-in
    [zzh.brd, zzh.sch]
2020-02-09 Revision A, Draft 3 check-in
    [zzh.brd, zzh.sch]
2020-02-09 debug-adapter, Revision A check-in
    [zzh-debug.brd, zzh-debug.sch]
2020-05-10 zzh: Revision A release
    [zzh.brd, zzh.sch]

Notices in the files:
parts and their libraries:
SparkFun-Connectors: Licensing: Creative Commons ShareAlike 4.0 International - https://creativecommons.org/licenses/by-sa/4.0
